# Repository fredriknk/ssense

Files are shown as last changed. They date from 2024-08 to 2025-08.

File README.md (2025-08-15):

# Mina Soilsense
 
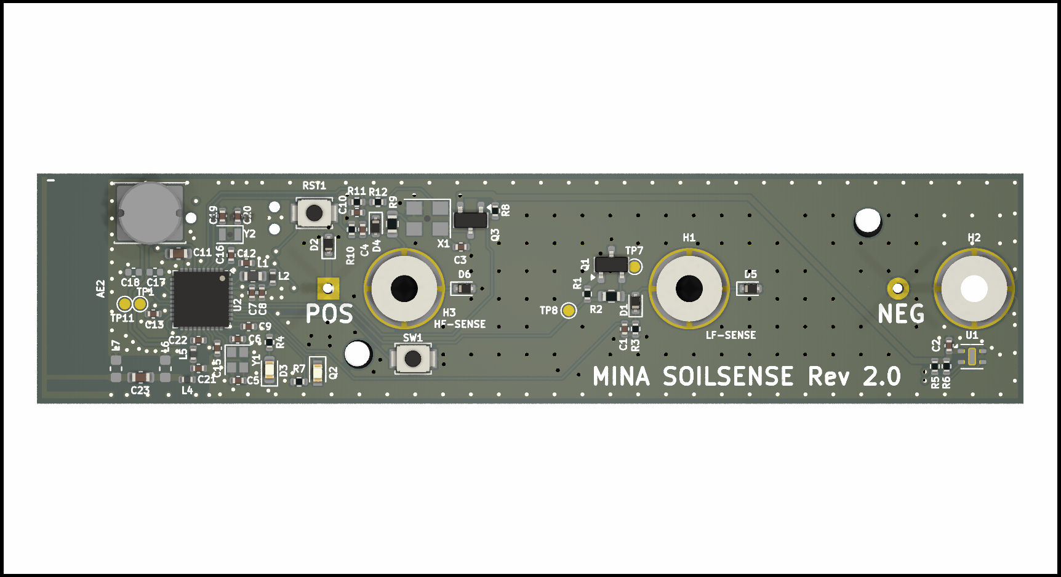
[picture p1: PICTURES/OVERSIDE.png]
HEADER


Open hardware for a Zigbee nrf52833 soil moisture probe, It is designed for using M3 stainless steel rods as probes screwed into the headers H1,H2,H3. It is designed to run on a 3.6v AA SAFT battery, average current is in the sub uA range when sampling 5 times per hour. So battery life should be in the range of 5-10 years. It has one 75mhz probe, one 1mhz probe (Variable frequency, so the plan is to do a frequency sweep with this to determine electrical conductivity in the medium) and a ground probe. It allso features a NFC coil, to pair the sensor with a gateway. And a temp sensor. 

Check out the ibom tool for component placement and hand soldering
[Assembly IBOM](https://htmlpreview.github.io/?https://raw.githubusercontent.com/fredriknk/ssense/main/DOCUMENTATION/ibom.html)

[PCB layout](./DOCUMENTATION/Board.pdf)

[SCHEMATIC](./DOCUMENTATION/Schematic.pdf)

## RF Testing

The antenna is simulated and optimized in matlab with [optimization script](https://github.com/fredriknk/antennasimulation) a theoretical -44dB S11, Actual measured S11 on the RF blanks is -26dB with a 0.5pF shunt capacotor soldered to L7 and a 0R resistor at C23. I left the antenna 1mm too long for tuning, but -26db is good enough for me. 

<p float="left">
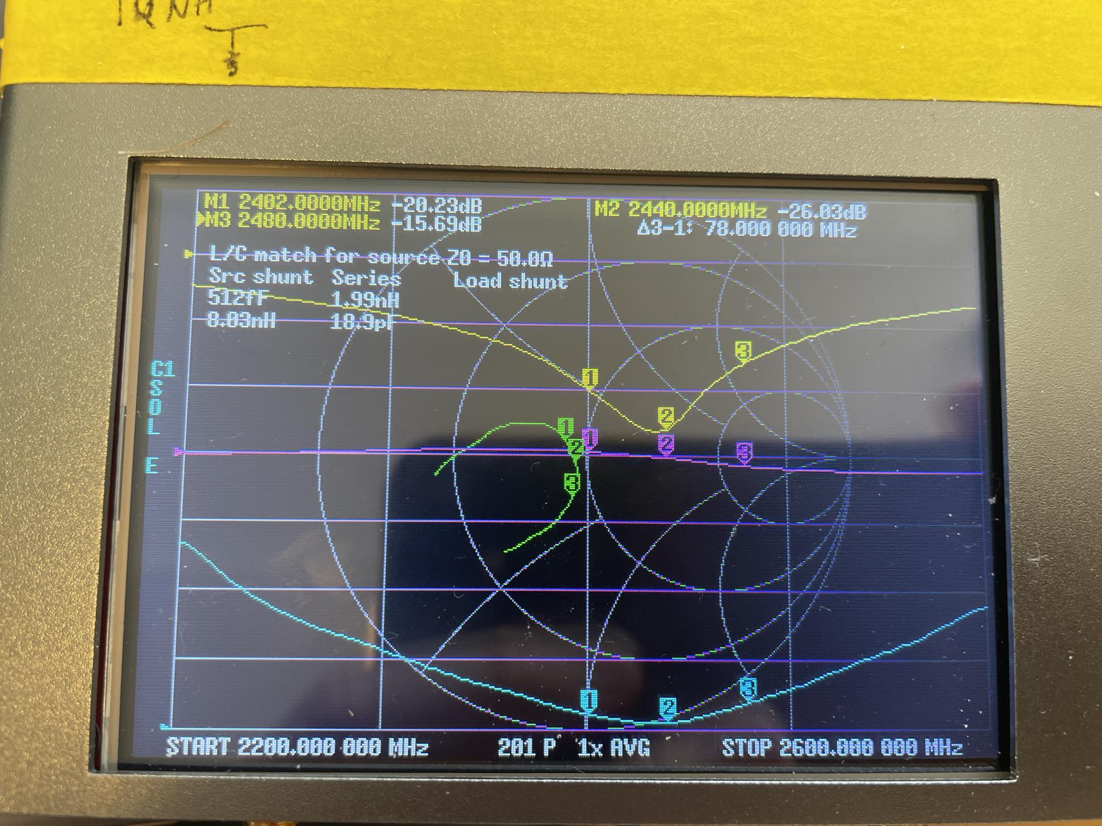
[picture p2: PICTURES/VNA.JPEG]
  
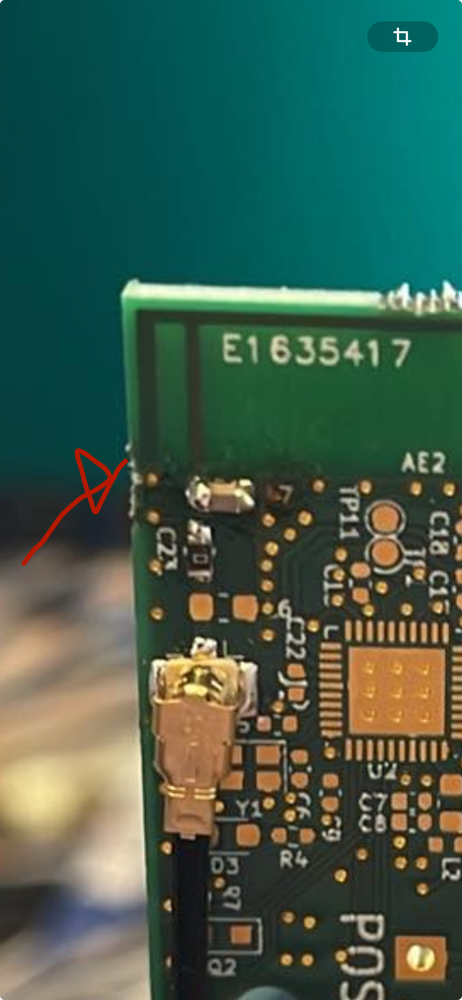
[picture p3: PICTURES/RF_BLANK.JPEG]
   
</p>

## Production run 1
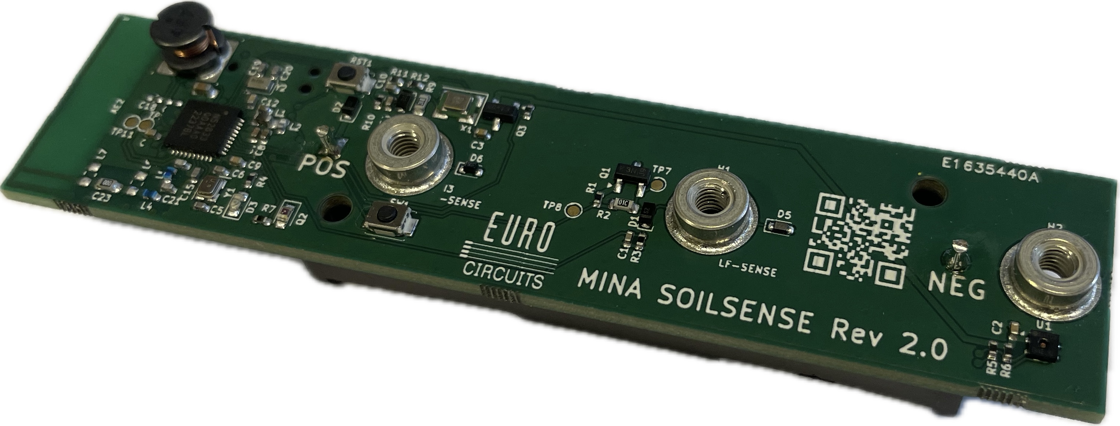
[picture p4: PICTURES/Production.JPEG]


Prototype produced at Eurocircuits

## Front

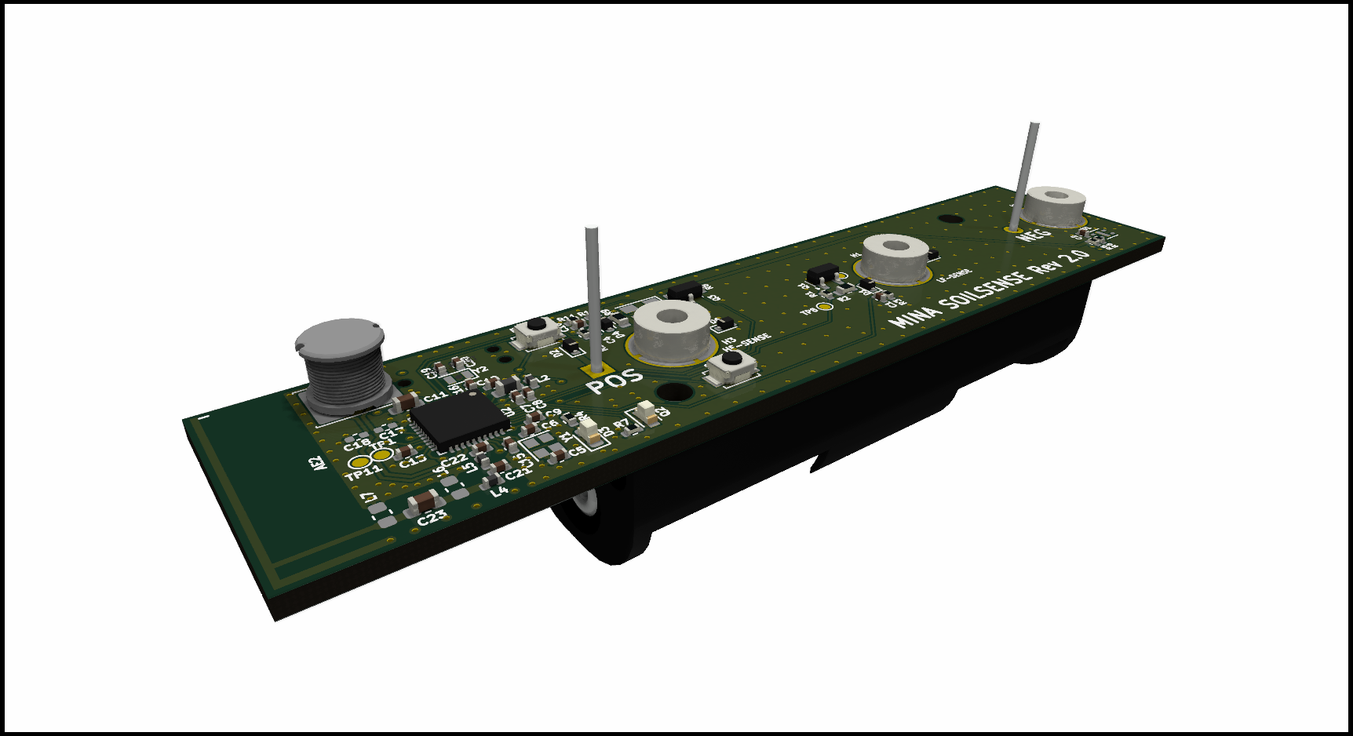
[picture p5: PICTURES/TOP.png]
Front


## Back

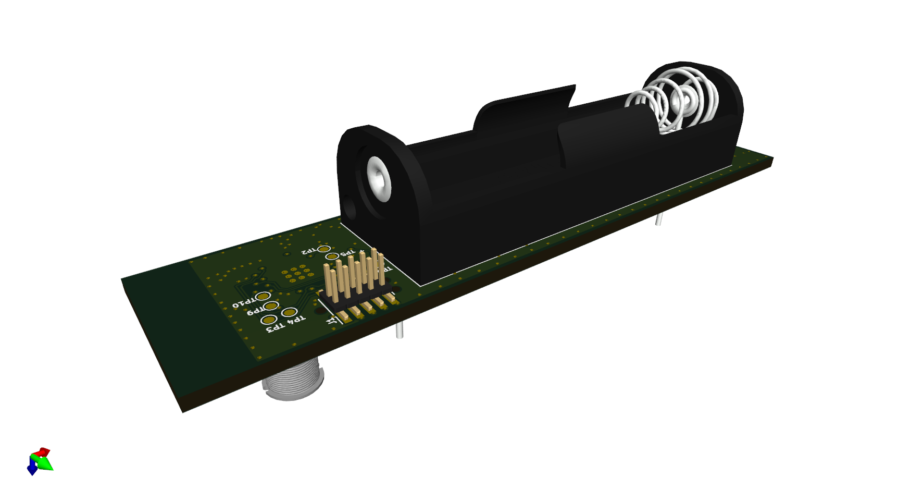
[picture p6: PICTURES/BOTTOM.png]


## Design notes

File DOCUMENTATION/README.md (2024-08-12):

## Use this folder for documentation, eg Schematics, datasheets, and stuff like that.

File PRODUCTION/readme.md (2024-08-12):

## All production files for latest revision of board

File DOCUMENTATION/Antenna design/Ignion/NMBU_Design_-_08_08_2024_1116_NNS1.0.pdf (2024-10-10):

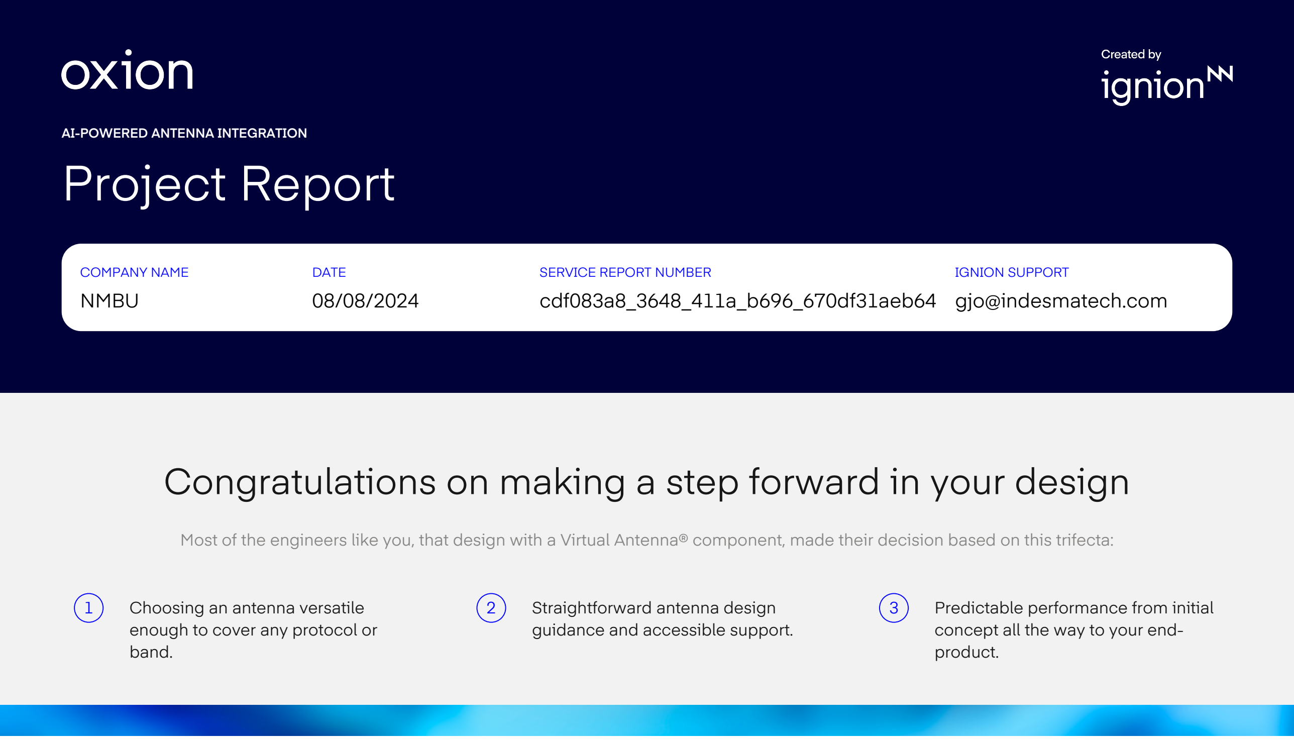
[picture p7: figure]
AI-POWERED ANTENNA INTEGRATION Project Report; COMPANY NAME NMBU; DATE 08/08/2024; SERVICE REPORT NUMBER cdf083a8_3648_411a_b696_670df31aeb64; IGNION SUPPORT gjo@indesmatech.com; Choosing an antenna versatile; enough to cover any protocol or band.; Straightforward antenna design; guidance and accessible support.; Predictable performance from initial; concept all the way to your end- product.

# Congratulations on making a step forward in your design

Most of the engineers like you, that design with a Virtual Antenna® component, made their decision based on this trifecta:

# Your requirements

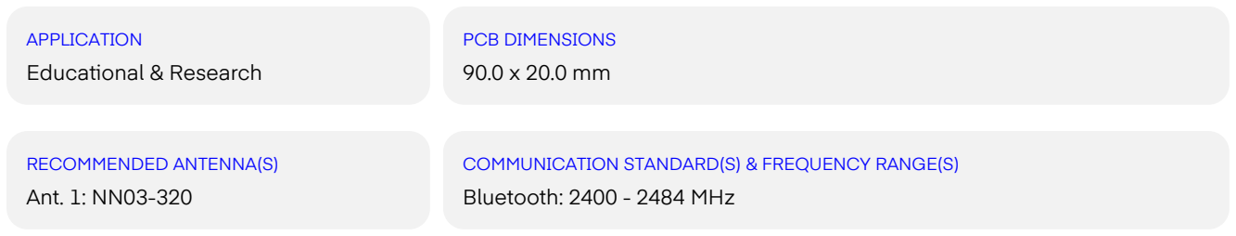
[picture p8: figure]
APPLICATION; Educational & Research; PCB DIMENSIONS; RECOMMENDED ANTENNA(S); Ant. 1: NN03-320; COMMUNICATION STANDARD(S) & FREQUENCY RANGE(S); Bluetooth: 2400 - 2484 MHz

# Best antenna placement on your PCB

Sketch of the proposed antenna placement and the recommended clearance area for the Virtual Antenna® component.

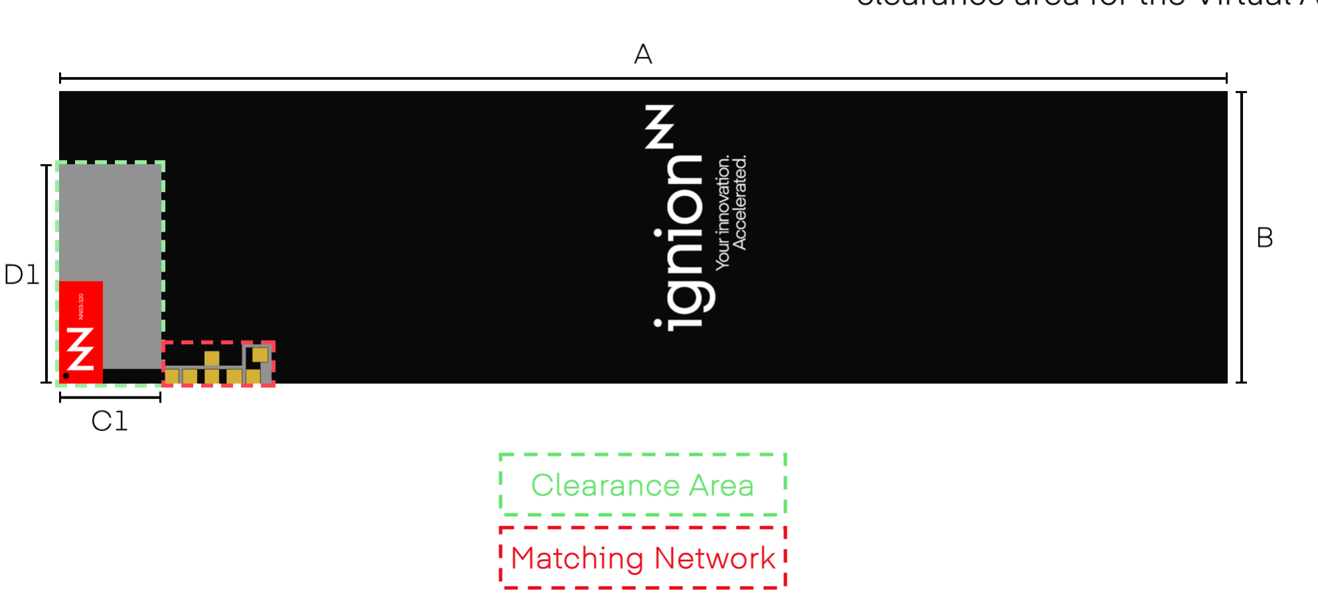
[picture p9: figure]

### PCB

Measure | mm
A | 90.0
B | 20.0

1: NN03-320

Measure | mm
C1 | 7.0
D1 | 15.0

The sketch above is an approximate representation of the PCB design. The accurate model can be found in the Desing_Files_NNS1.0.zip attached in the same email where the report was received.

1

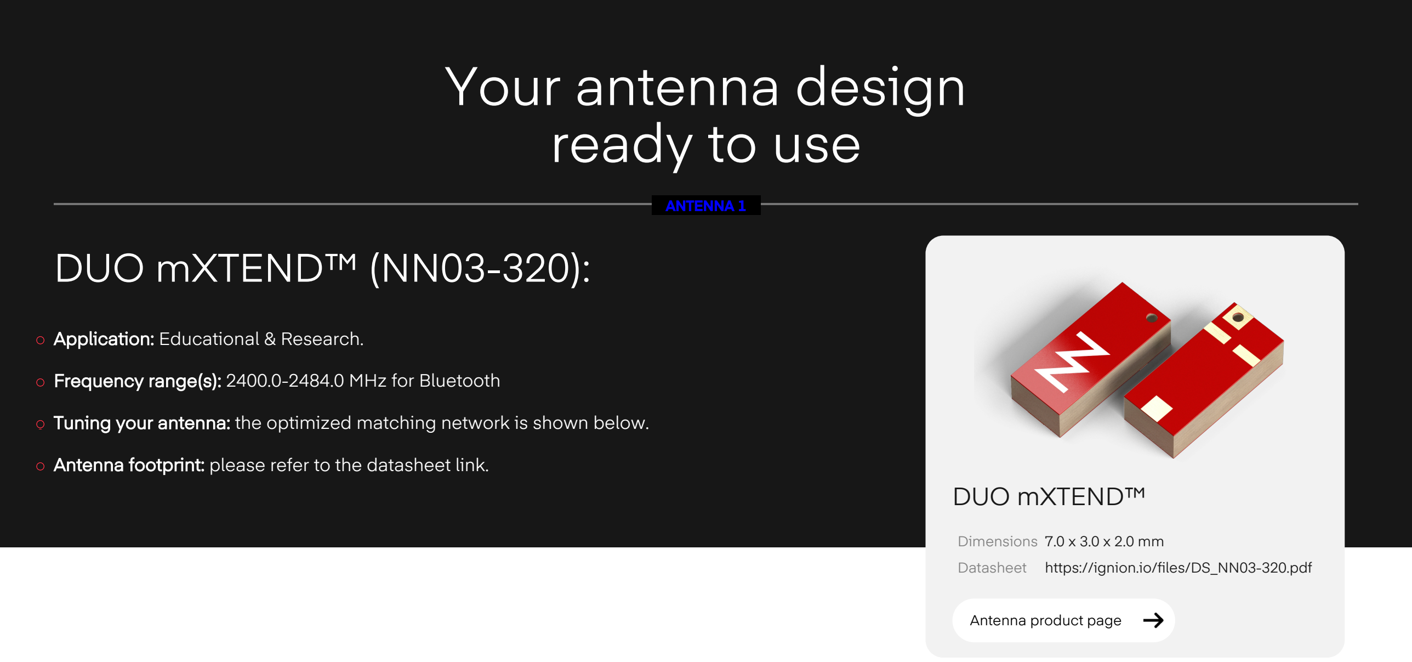
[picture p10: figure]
Your antenna design ready to use; ANTENNA 1; DUO mXTEND™ (NN03-320):; Application: Educational & Research.; DUO mXTEND™; Dimensions 7.0 x 3.0 x 2.0 mm; Datasheet; https://ignion.io/files/DS_NN03-320.pdf; Antenna product page

Frequency range(s): 2400.0-2484.0 MHz for Bluetooth

Tuning your antenna: the optimized matching network is shown below.

Antenna footprint: please refer to the datasheet link.

# Matching network antenna 1

Bluetooth matching network topology

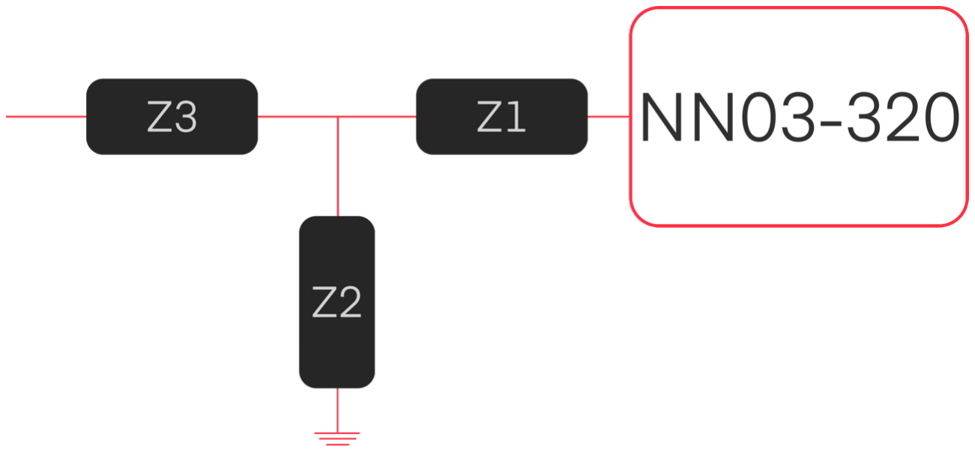
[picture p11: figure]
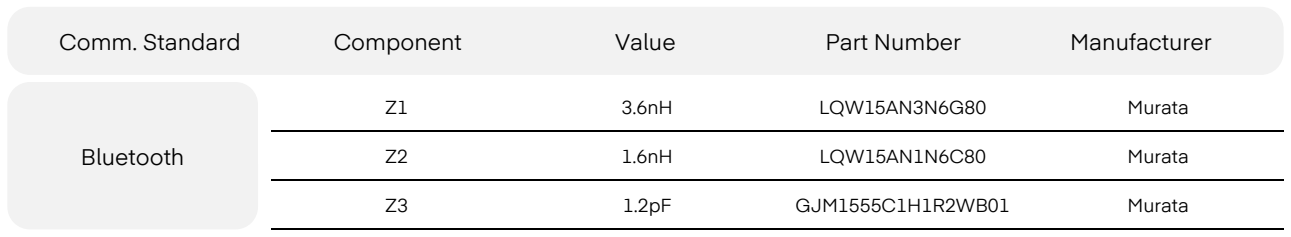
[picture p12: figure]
Bluetooth; LQW15AN3N6G80; Murata; LQW15AN1N6C80; GJM1555C1H1R2WB01

Comm. Standard | Component | Value | Part Number | Manufacturer

The electronic component values correspond with the matching network when implemented on a bare PCB. These values may need further tuning and optimization when additional elements such as batteries, plastic covers, connectors, displays, etc. are added to your final device.

If you need further assistance, please contact our antenna specialists.

GET HELP | 2

# Your antenna design ready to use

ANTENNA 1

# Your design overall performance

# Expected device performance with antenna 1

Your prototype using the NN03-320 antenna is expected to achieve the reflection coefficient (in dB) and total efficiency (in %) as shown in this graph.

Rule of thumb: it is desirable to have a reflection coefficient below -6 dB, ensuring proper impedance matching of the antenna component and optimized
total efficiency.

INCREASE YOUR PERFORMANCE: to increase the performance we recommend evaluating your PCB again with increased dimensions (increasing length by 10 mm typically results in a total efficiency improvement of 0.5 dB).

Frequency (MHz) | 2400 | 2484 | Avg 2400 - 2484

If you need further assistance, please contact our antenna specialists.

GET HELP | 3

# General design recommendations

### for performance optimization with Virtual Antenna® technology

Consider the recommended clearance area in all directions around the antenna component. It must be free from electronic components, traces and ground plane in all PCB layers including the area underneath the antenna.

### 2 ANTENNA LOCATION

Keep the antenna in a corner of the PCB, as far as possible from other metalic components.

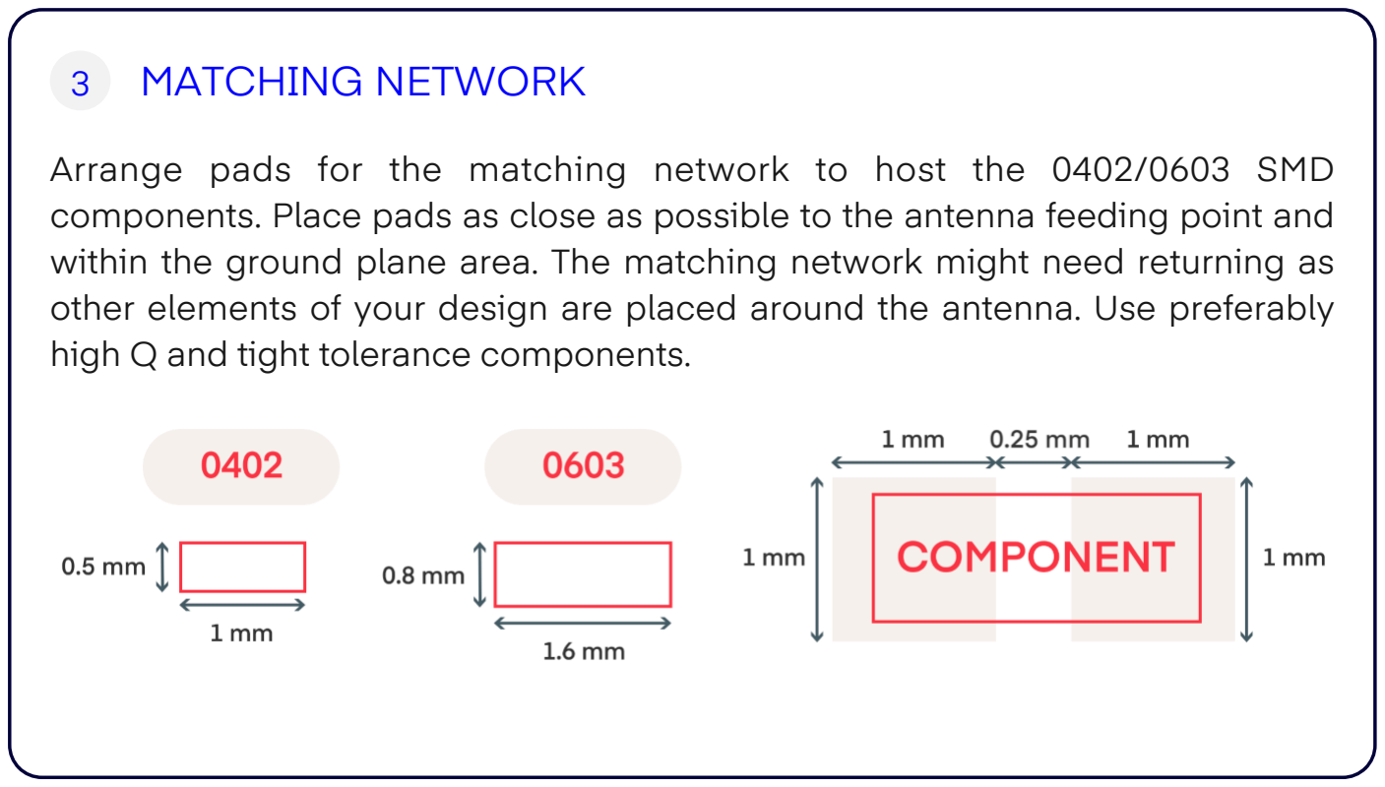
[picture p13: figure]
MATCHING NETWORK; high Q and tight tolerance components.

Arrange pads for the matching network to host the 0402/0603 SMD components. Place pads as close as possible to the antenna feeding point and within the ground plane area. The matching network might need returning as other elements of your design are placed around the antenna. Use preferably

### 4 MATERIALS

Use low loss materials (i.e. PET plastic, Polyethylene Terephthalate) for the housings and enclosures.

### 5 MULTI-LAYER PCBs

Ensure that all the grounding sections in every PCB layer are properly connected through vias.

### 6 TRANSMISSION LINE AND RF CHIP

Design your transmission line connecting the matching network to your RF chip so that its characteristic impedance is 50 Ohms. Locate your RF chip as close as possible to the matching network to reduce losses.

### 7 GROUND PLANE LAYER

Ensure a continuous conducting ground plane in at least one layer of your PCB. Always maximize the surface of your ground area on the PCB of your device to maximize its radiation performance.

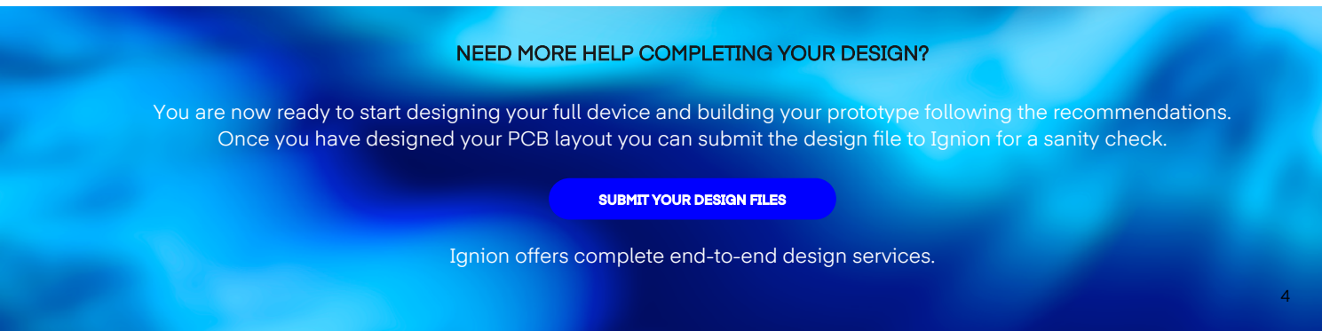
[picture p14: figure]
NEED MORE HELP COMPLETING YOUR DESIGN?; SUBMIT YOUR DESIGN FILES

You are now ready to start designing your full device and building your prototype following the recommendations. Once you have designed your PCB layout you can submit the design file to Ignion for a sanity check.

Ignion offers complete end-to-end design services.

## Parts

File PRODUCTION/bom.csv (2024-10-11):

Designator | Footprint | Quantity | Value | LCSC Part #
BT1 | BatteryHolder_Keystone_2460_1xAA | 1 | Keystone 2460 | 2460
C1, C10, C4 | 0402 | 3 | 1nF
C11 | 0603 | 1 | 4.7uF
C12, C8 | 0402 | 2 | 1uF
C13, C16, C2, C3, C9 | 0402 | 5 | 100nF
C15 | 0402 | 1 | 100pF
C19, C20, C5, C6 | 0402 | 4 | 12pF
C21 | 0402 | 1 | 1.2pF
C22 | 0402 | 1 | 1.0pF
C23 | 0603 | 1 | 0R placeholder
C7 | 0402 | 1 | 47nF
D1, D2, D4 | D_SOD-523 | 3 | CDSU101A | CDSU101A
D3 | 0603 | 1 | LED
D5, D6 | D_SOD-523 | 2 | Zener Prot 5V | EDZVT2R5.1B
H1, H2, H3 | Mounting_Wuerth_WA-SMSI-M3_H2.5mm_9774025360 | 3 | 9774025360R | 9774025360R
J1 | SEXY_pinpogo | 1 | JLINK
L1 | 0603 | 1 | 10uH
L2 | 0402 | 1 | 15nH | MLG1005S15NHT000
L3 | L_Bourns_SDSS604A | 1 | 4.7uH | SDR0604-4R7ML
L4 | 0402 | 1 | 2.2nH | LQW15AN2N2C80D
L5 | 0402 | 1 | 4.7nH | LQW15AN4N7C80D
Q1 | SOT-23 | 1 | MMBT3906
Q2 | PHOTOTRANS_1708Metric | 1 | Q_Photo_NPN | ALS-PT19-315C/L177/TR8
Q3 | SOT-23 | 1 | IRLML6401 | IRLML6401
R1, R11, R12, R5, R6, R8 | 0402 | 6 | 10k
R10, R3 | 0402 | 2 | 1M
R2, R9 | 0603 | 2 | 10k
R4 | 0402 | 1 | 1k
R7 | 0402 | 1 | 470R
RST1, SW1 | SW_SPST_B3U-1000P-B | 2 | B3U-1000P
U1 | Sensirion_DFN-4-1EP_2x2mm_P1mm_EP0.7x1.6mm | 1 | SHTC3
U2 | QFN-40-1EP_5x5mm_P0.4mm_EP3.6x3.6mm_ThermalVias | 1 | nRF52833_QDxx | nRF52833_QDAA
X1 | Oscillator_SMD_SeikoEpson_SG8002CE-4Pin_3.2x2.5mm | 1 | KC3225K75.0000C1GE00 | KC3225K75.0000C1GE00
Y1 | Crystal_SMD_2016-4Pin_2.0x1.6mm | 1 | 32MHz | XRCGB32M000F2P01R0
Y2 | Crystal_SMD_2012-2Pin_2.0x1.2mm | 1 | 32.768kHz | CM8V-T1A-32.768KHZ-9PF-20PPM-TA-QC

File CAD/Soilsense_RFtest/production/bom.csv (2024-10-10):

Designator | Footprint | Quantity | Value | LCSC Part #
BT1 | BatteryHolder_Keystone_2460_1xAA | 1 | Keystone 2460 | 2460
C23 | 0603 | 1 | 0R placeholder
H1, H2, H3 | Mounting_Wuerth_WA-SMSI-M3_H2.5mm_9774025360 | 3 | 9774025360R | 9774025360R
J2 | U.FL_Hirose_U.FL-R-SMT-1_Vertical | 1 | Conn_Coaxial

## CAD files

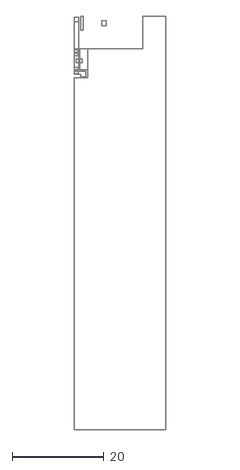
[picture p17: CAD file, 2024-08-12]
DOCUMENTATION/Antenna design/Ignion/Top.dxf
20.0 x 90.0

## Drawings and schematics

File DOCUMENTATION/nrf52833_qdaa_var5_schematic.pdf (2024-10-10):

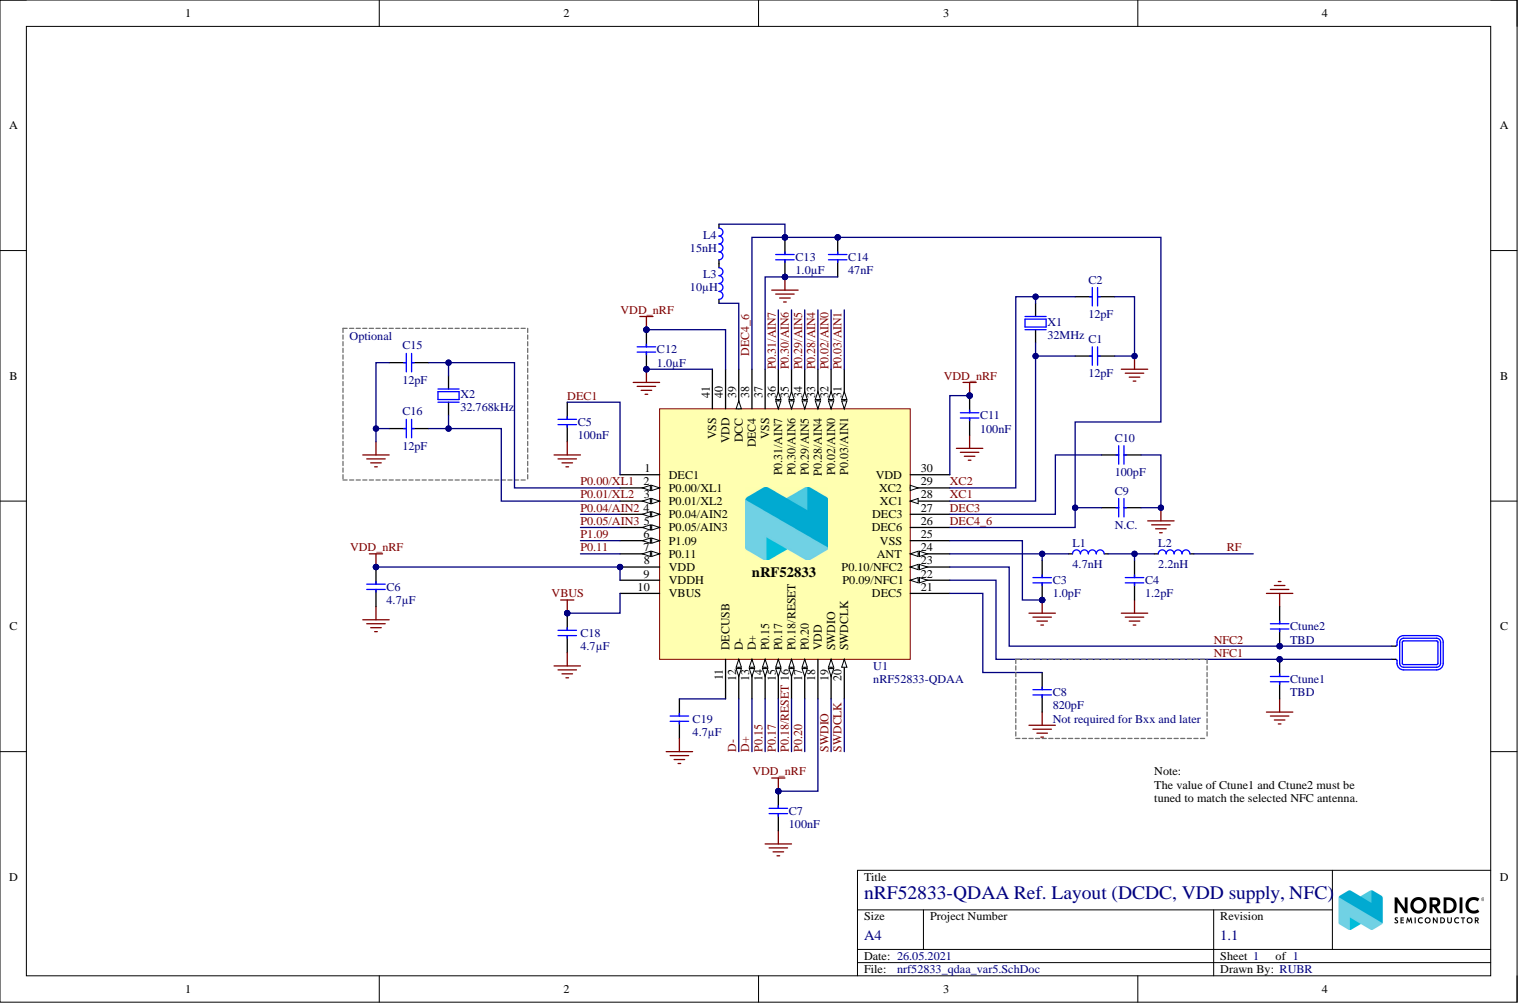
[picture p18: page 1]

VBUS 10

NFC1

Not required for Bxx and later

Note:
The value of Ctune1 and Ctune2 must be
tuned to match the selected NFC antenna.

Title
nRF52833-QDAA Ref. Layout (DCDC, VDD supply, NFC)

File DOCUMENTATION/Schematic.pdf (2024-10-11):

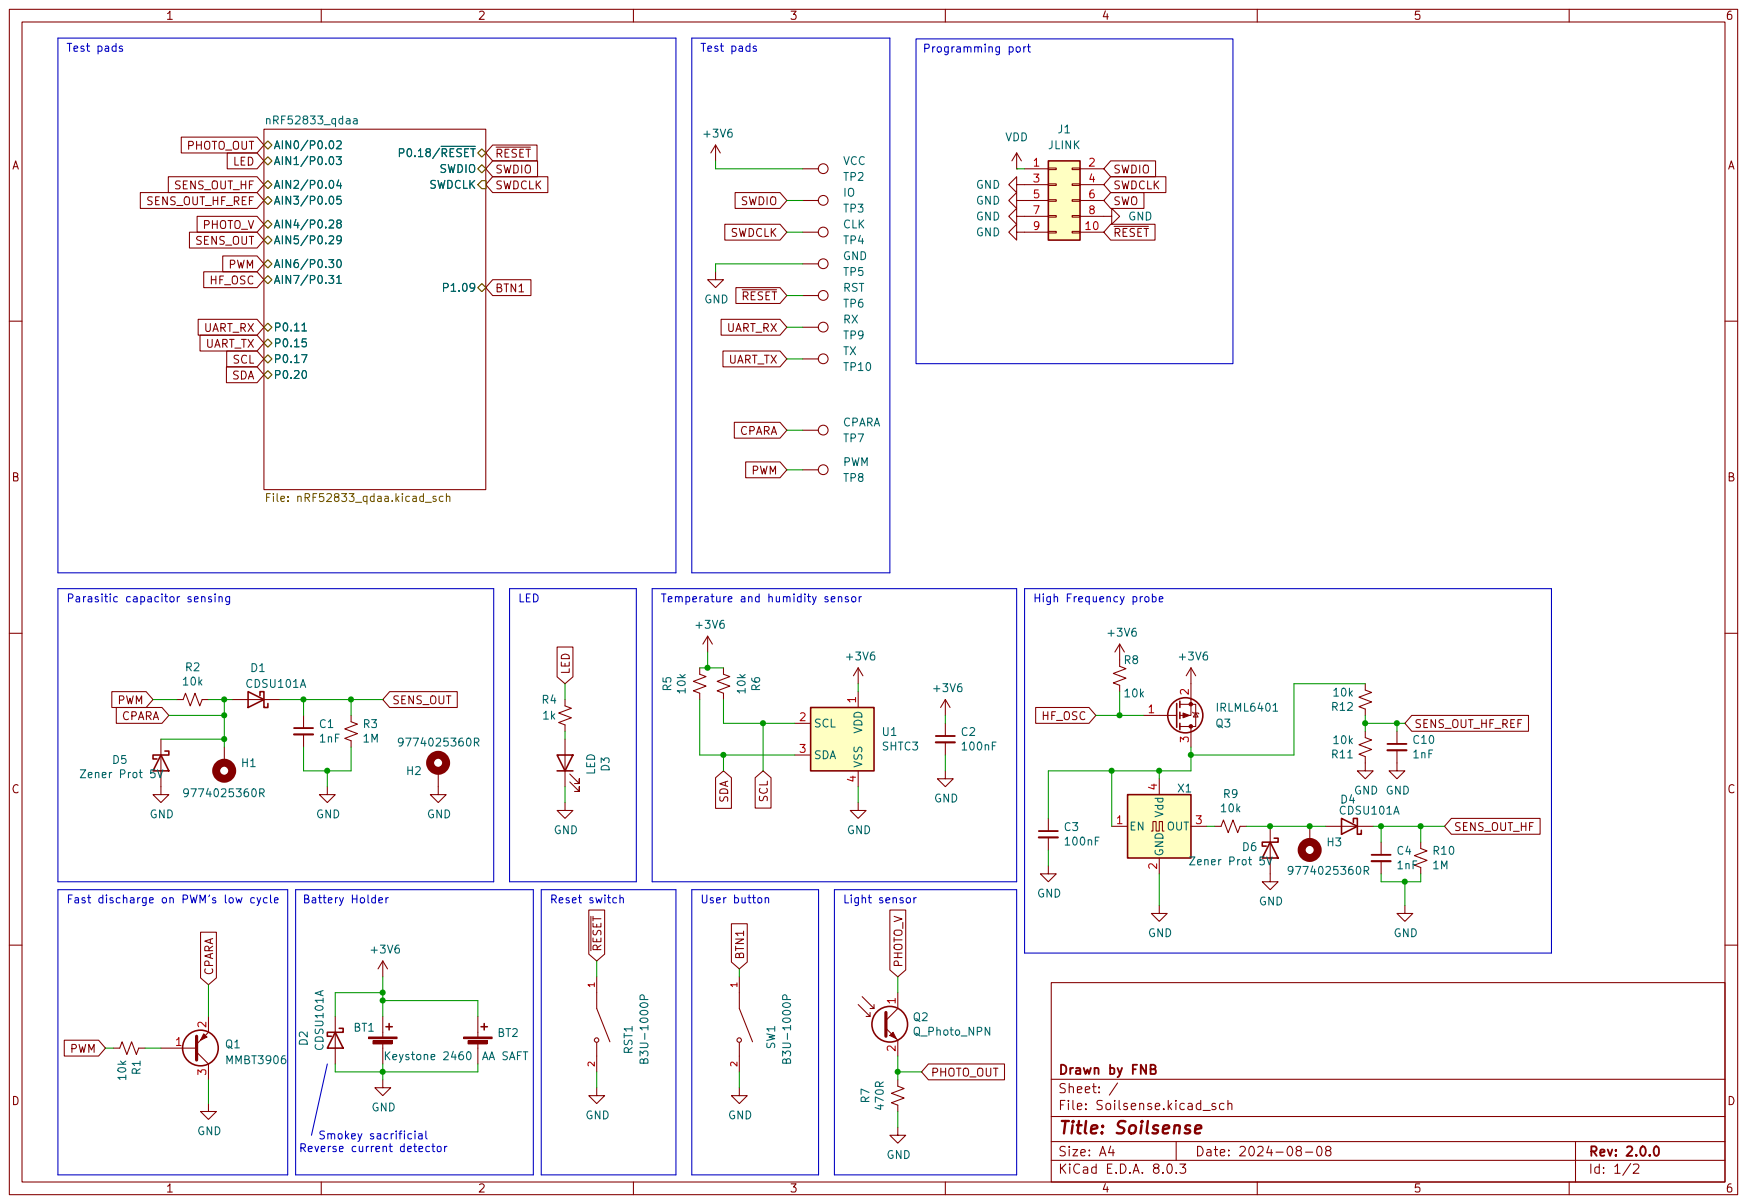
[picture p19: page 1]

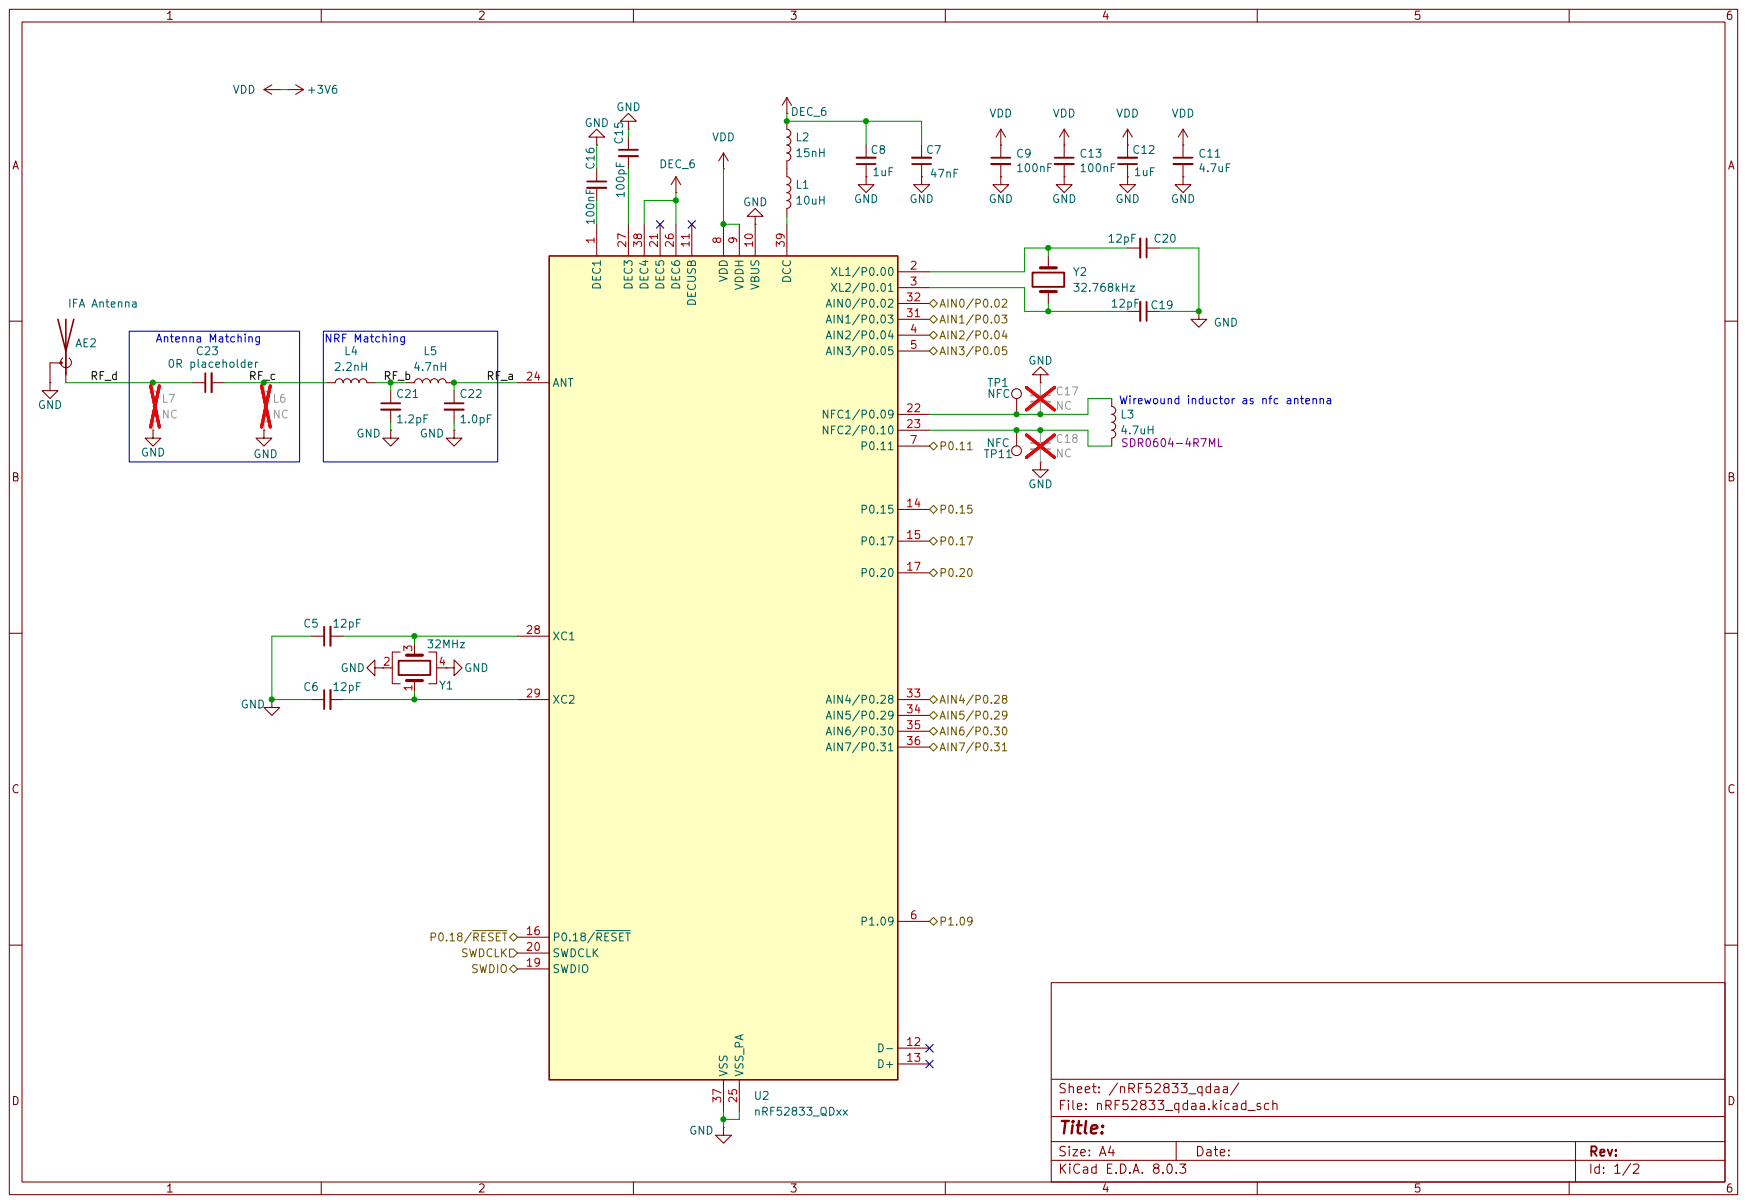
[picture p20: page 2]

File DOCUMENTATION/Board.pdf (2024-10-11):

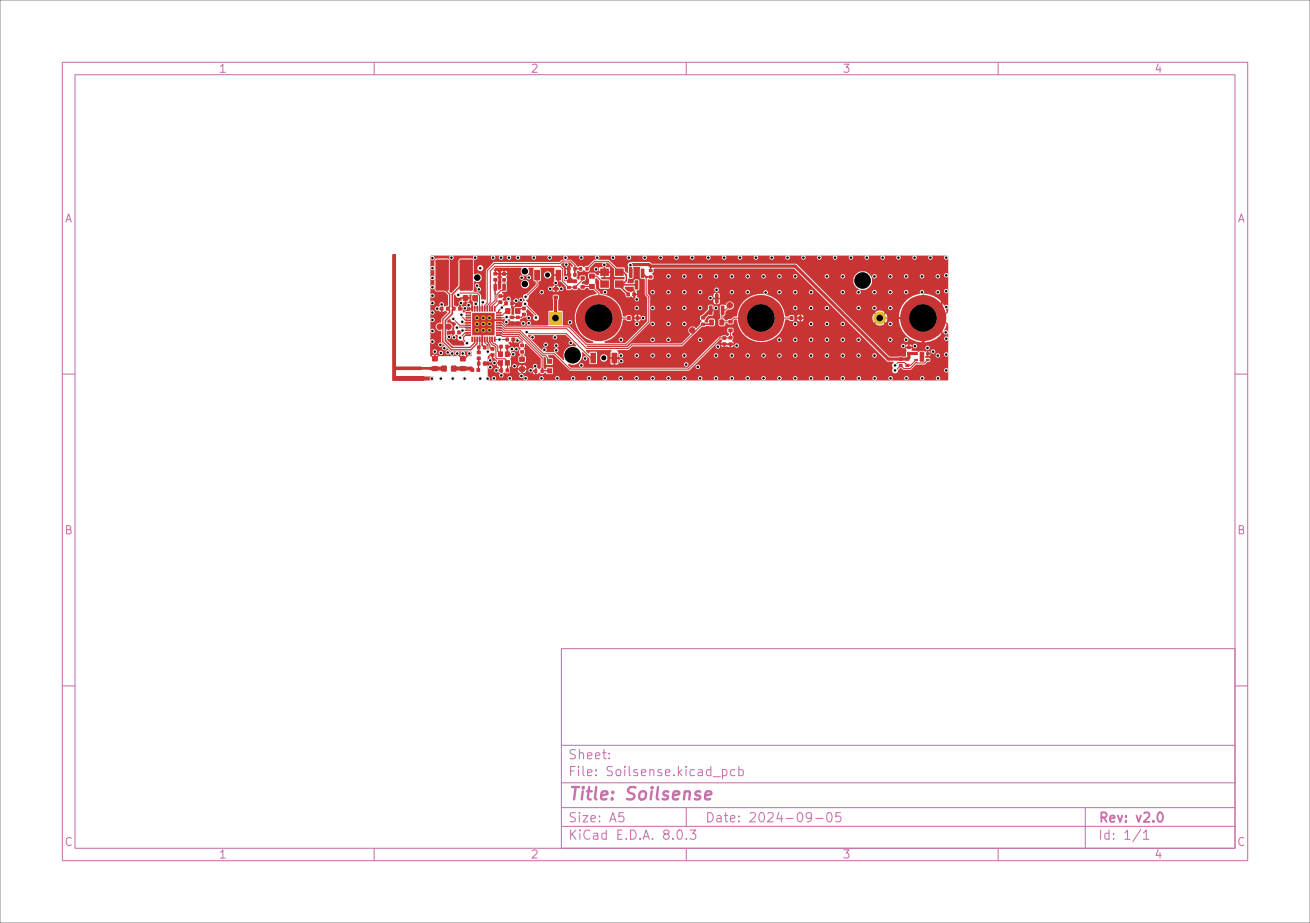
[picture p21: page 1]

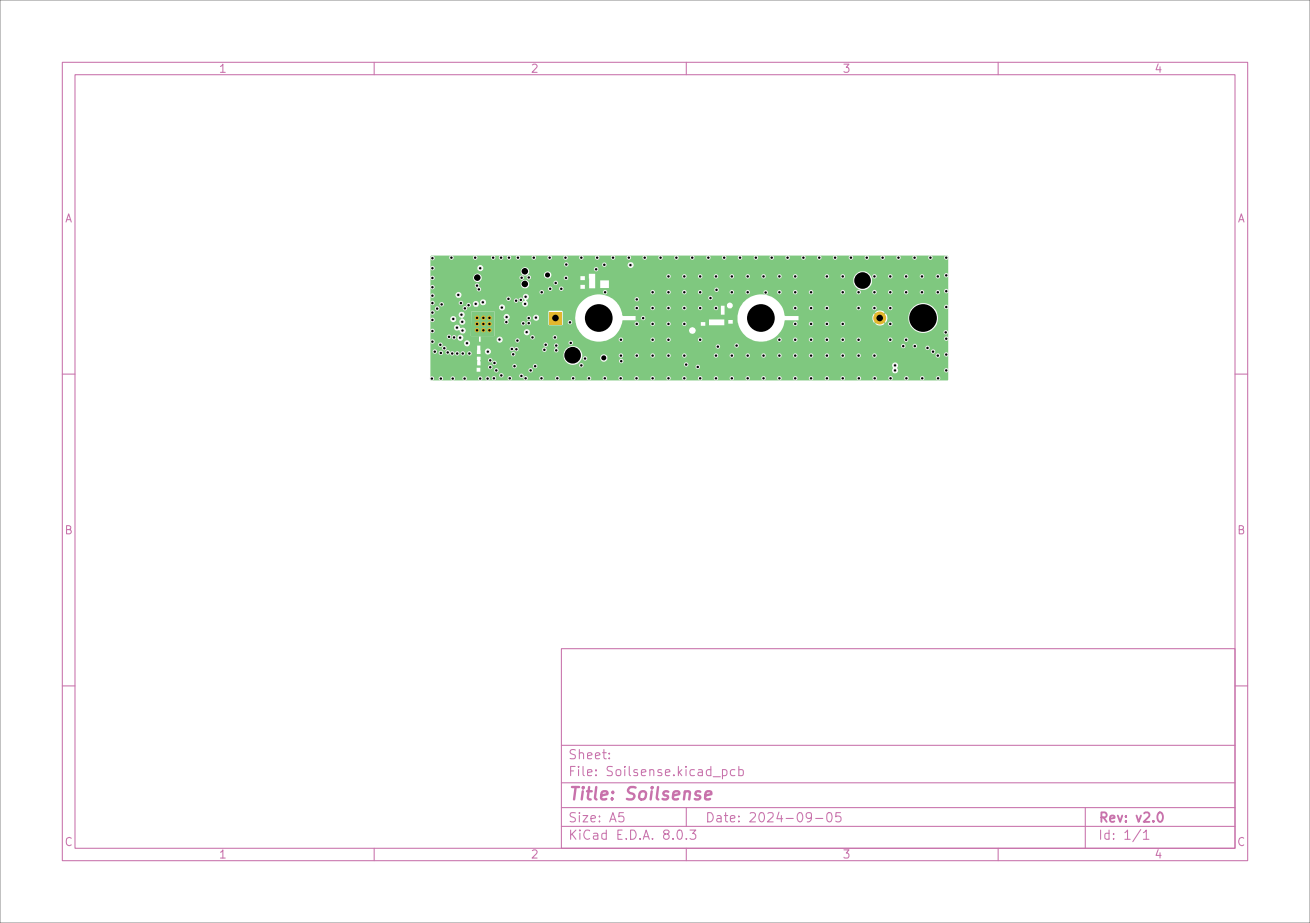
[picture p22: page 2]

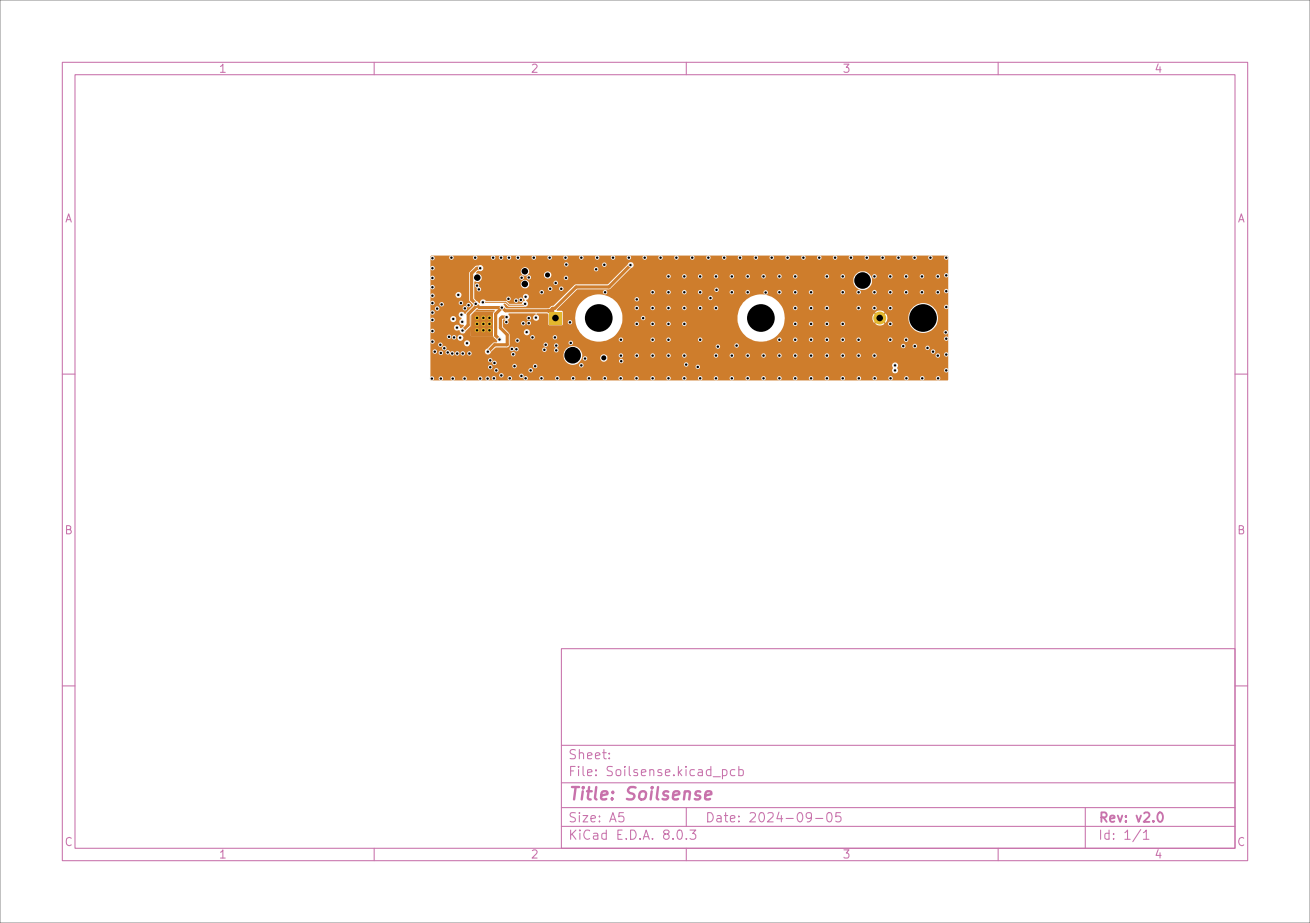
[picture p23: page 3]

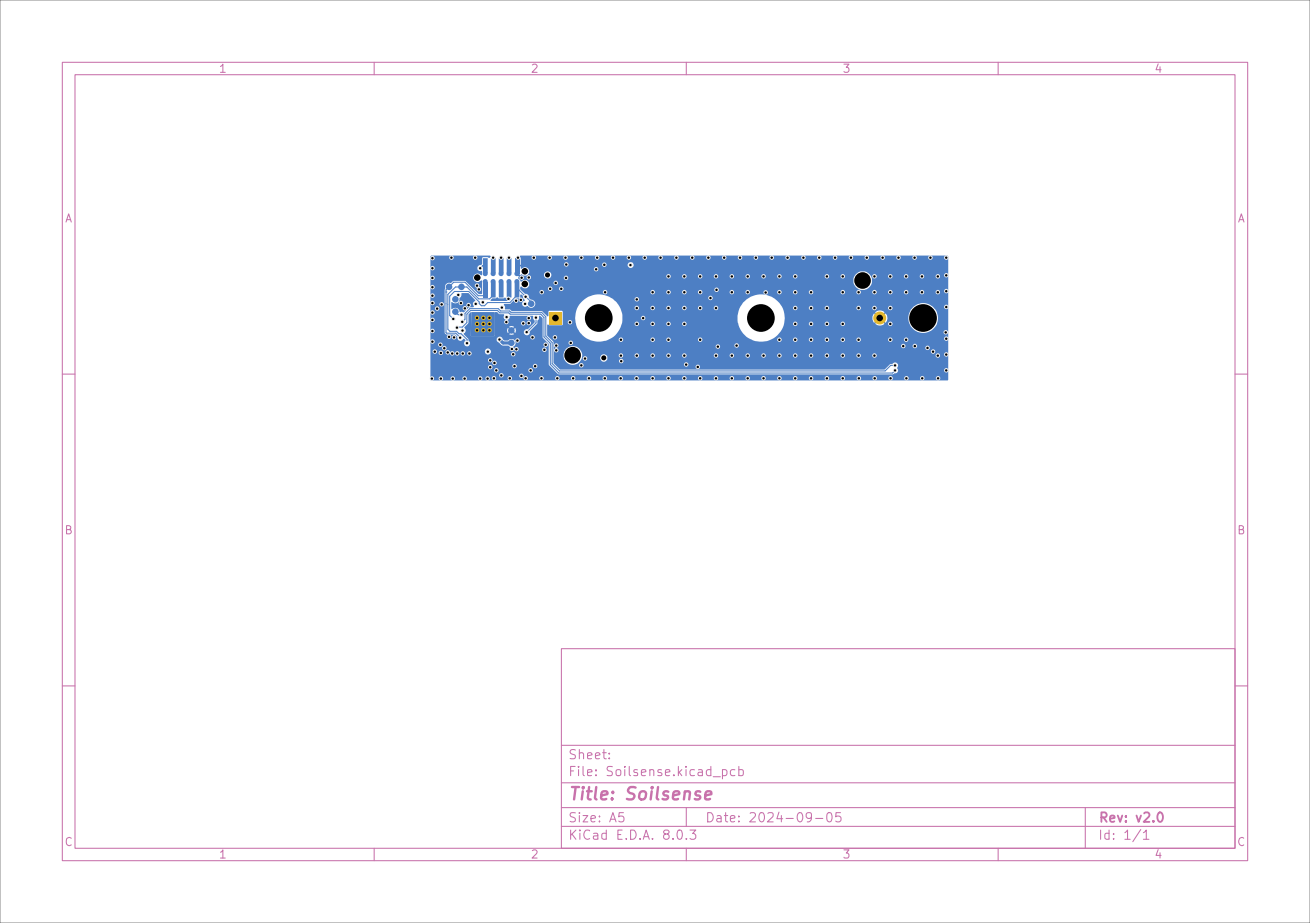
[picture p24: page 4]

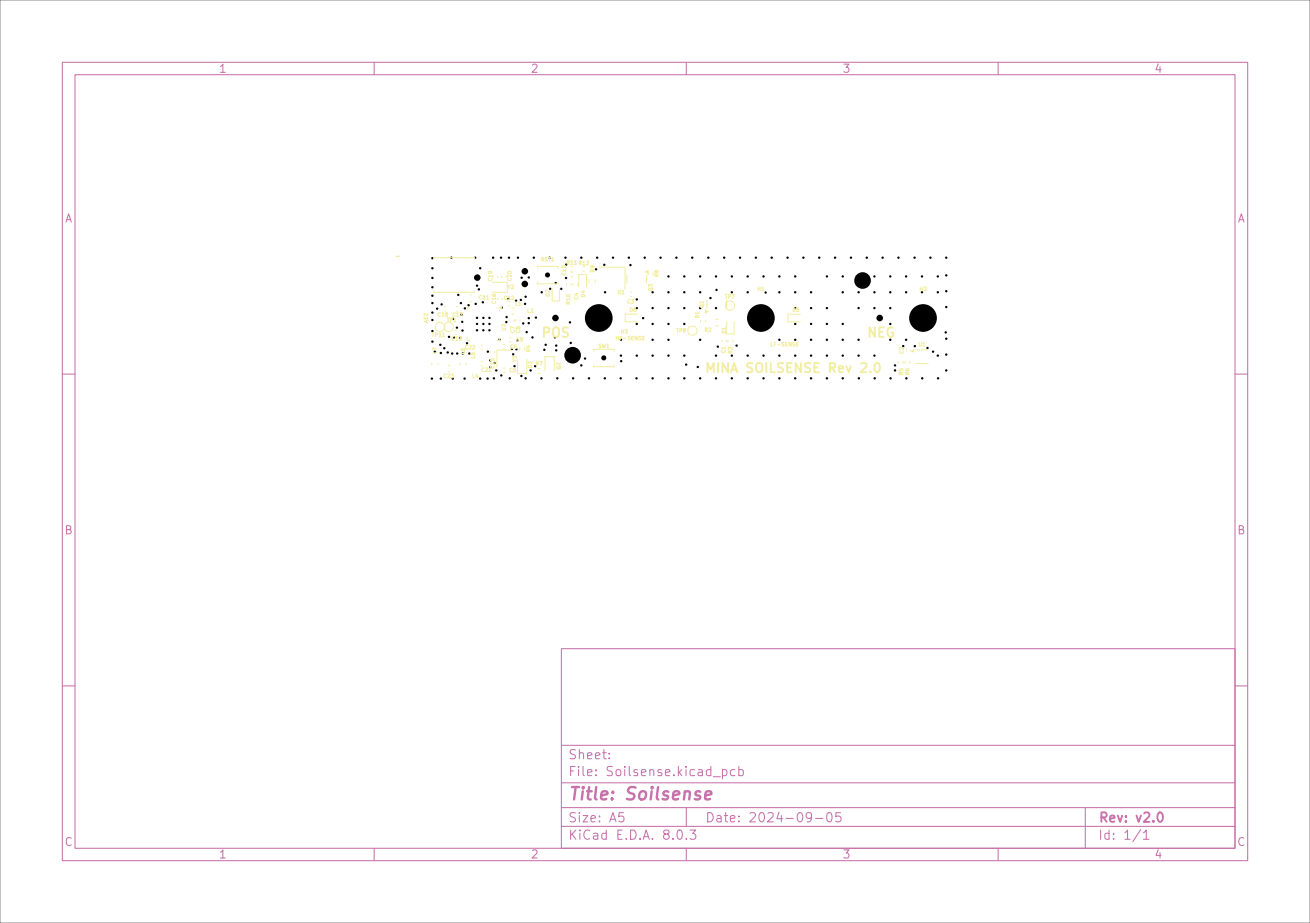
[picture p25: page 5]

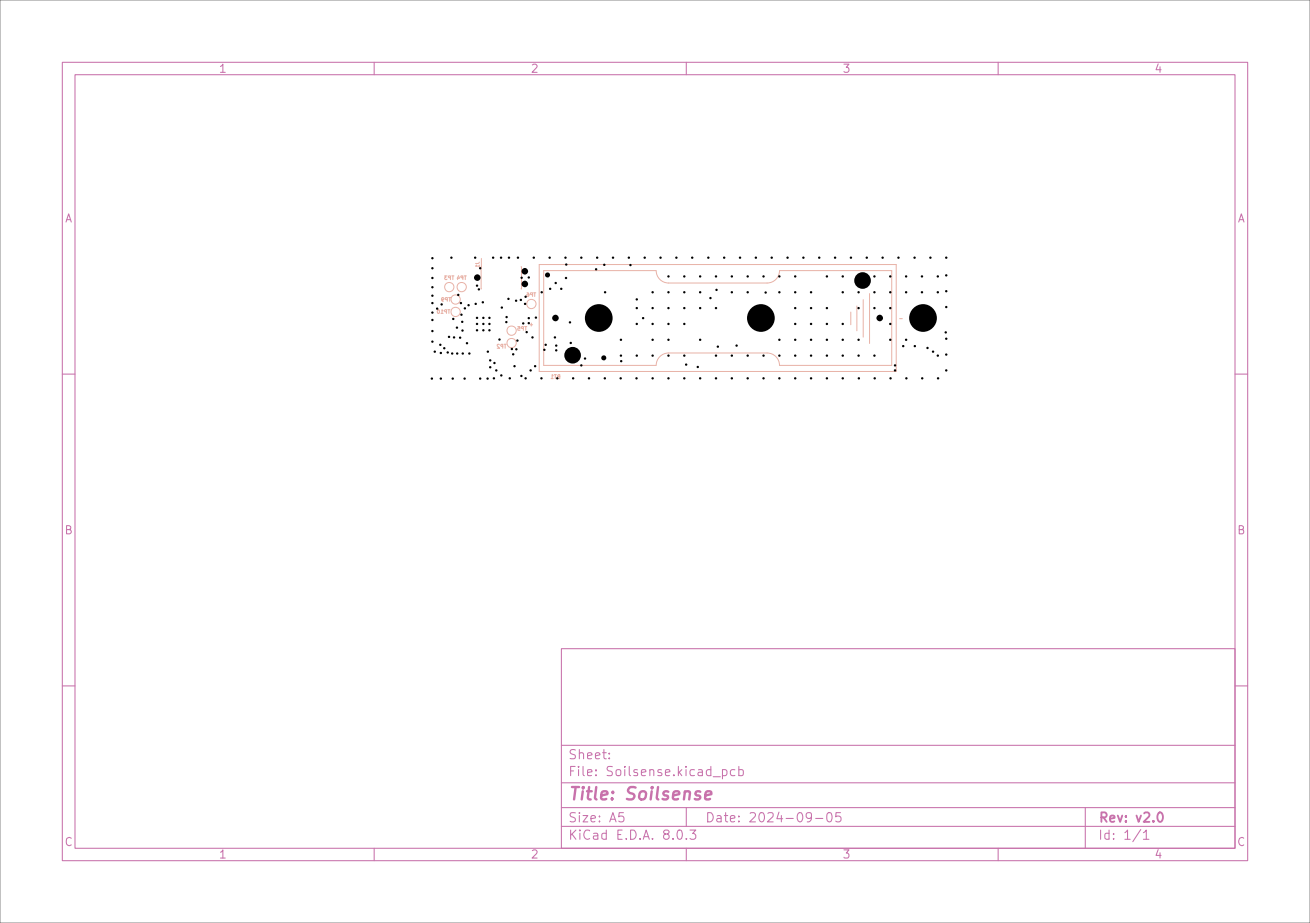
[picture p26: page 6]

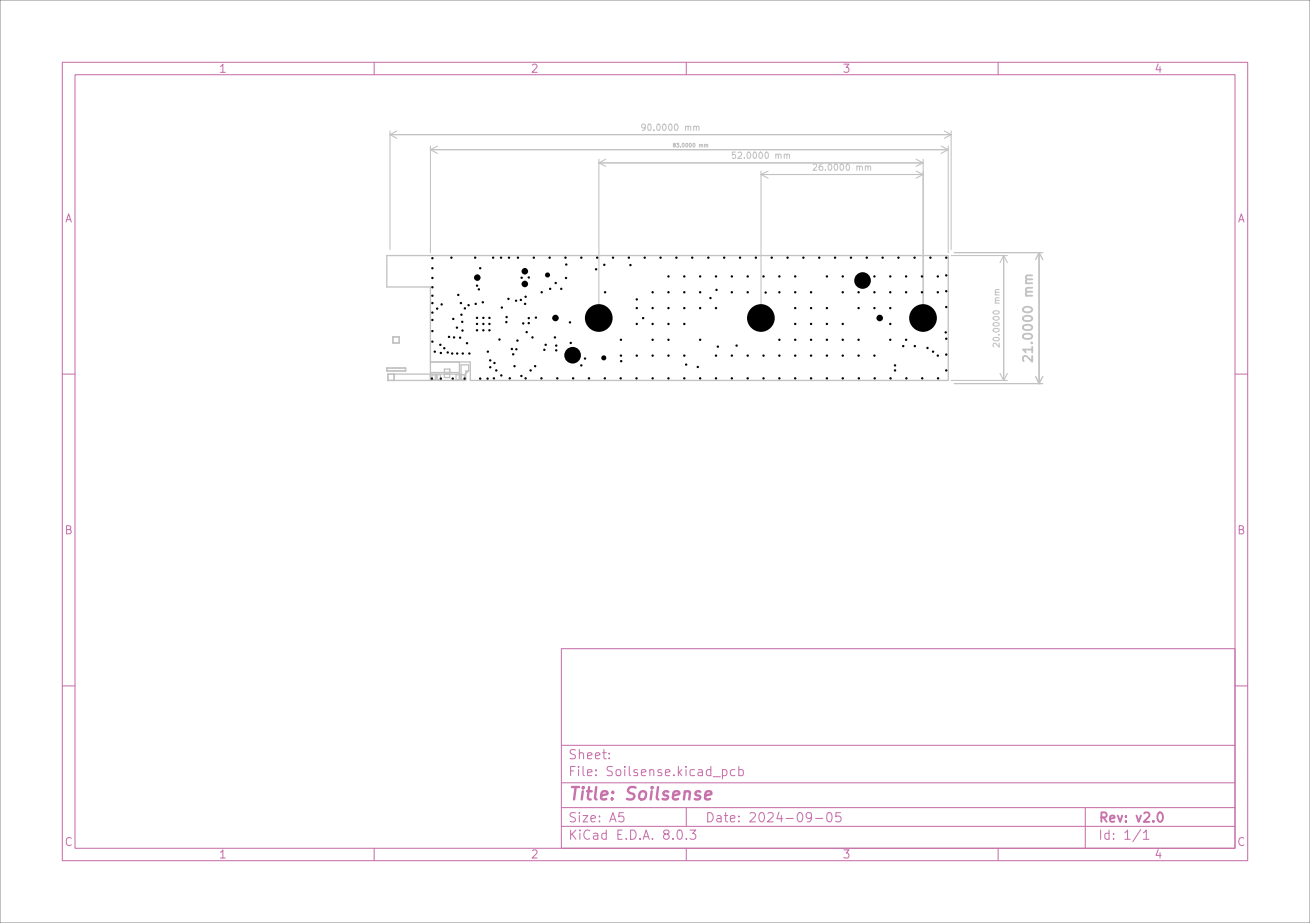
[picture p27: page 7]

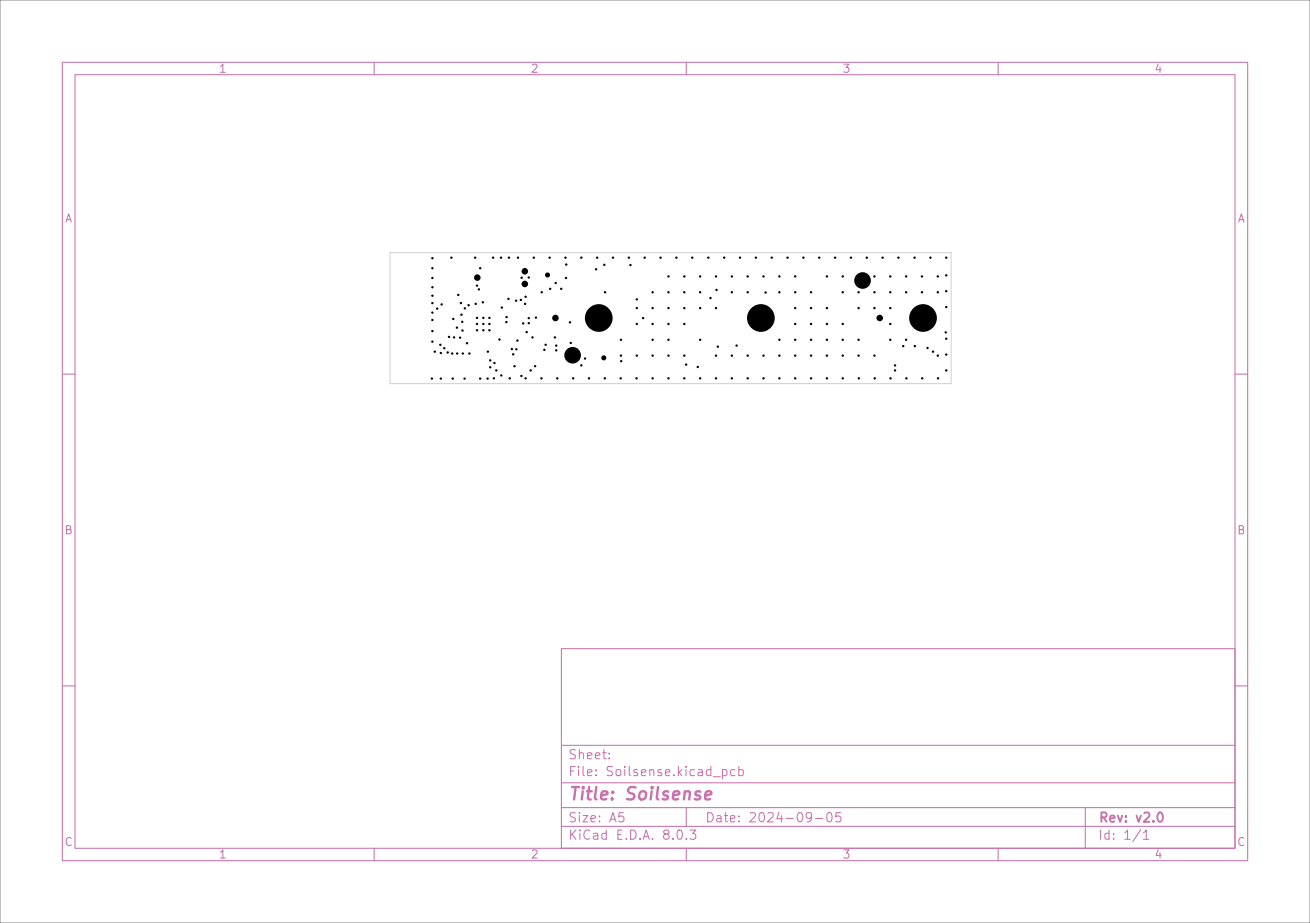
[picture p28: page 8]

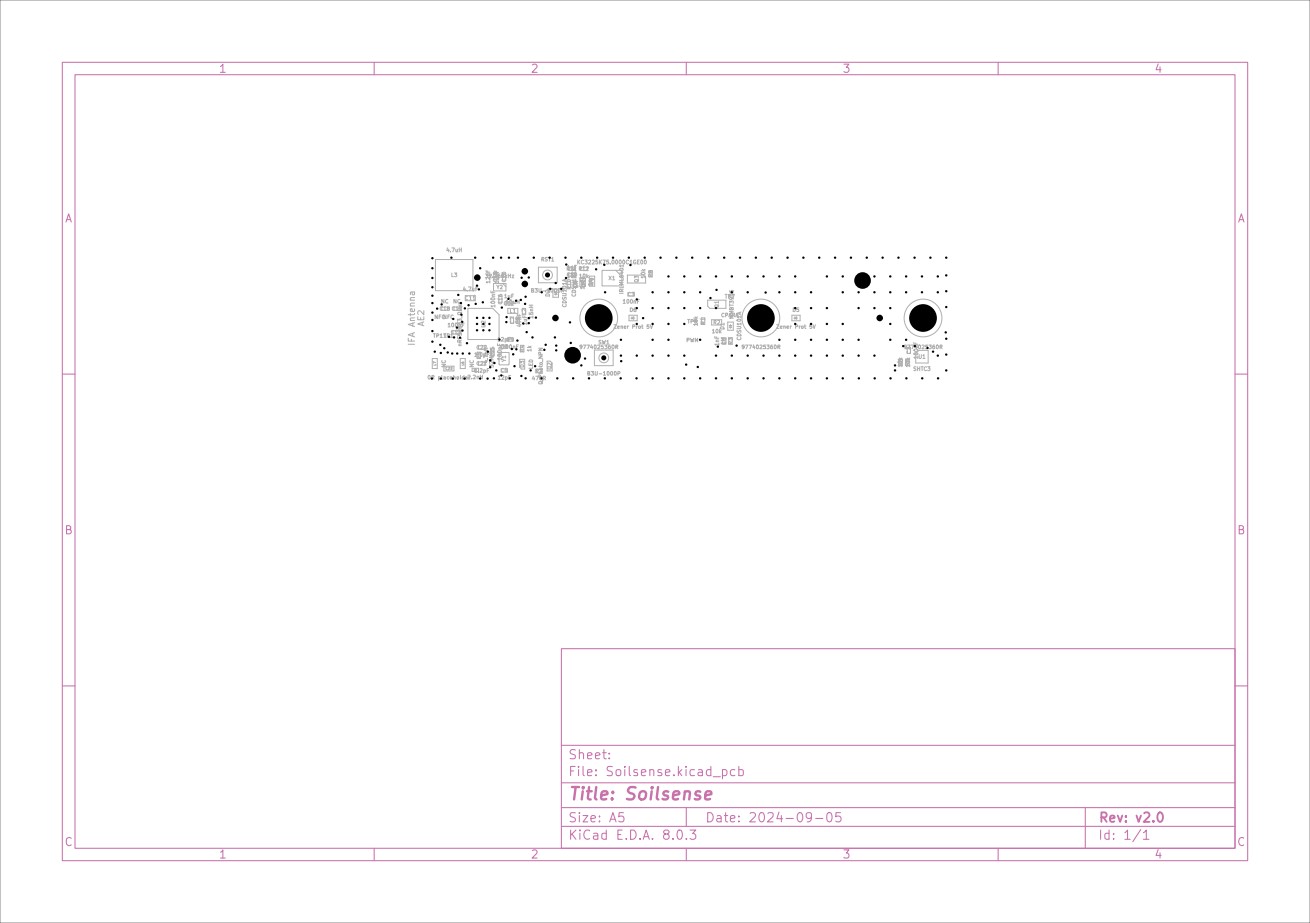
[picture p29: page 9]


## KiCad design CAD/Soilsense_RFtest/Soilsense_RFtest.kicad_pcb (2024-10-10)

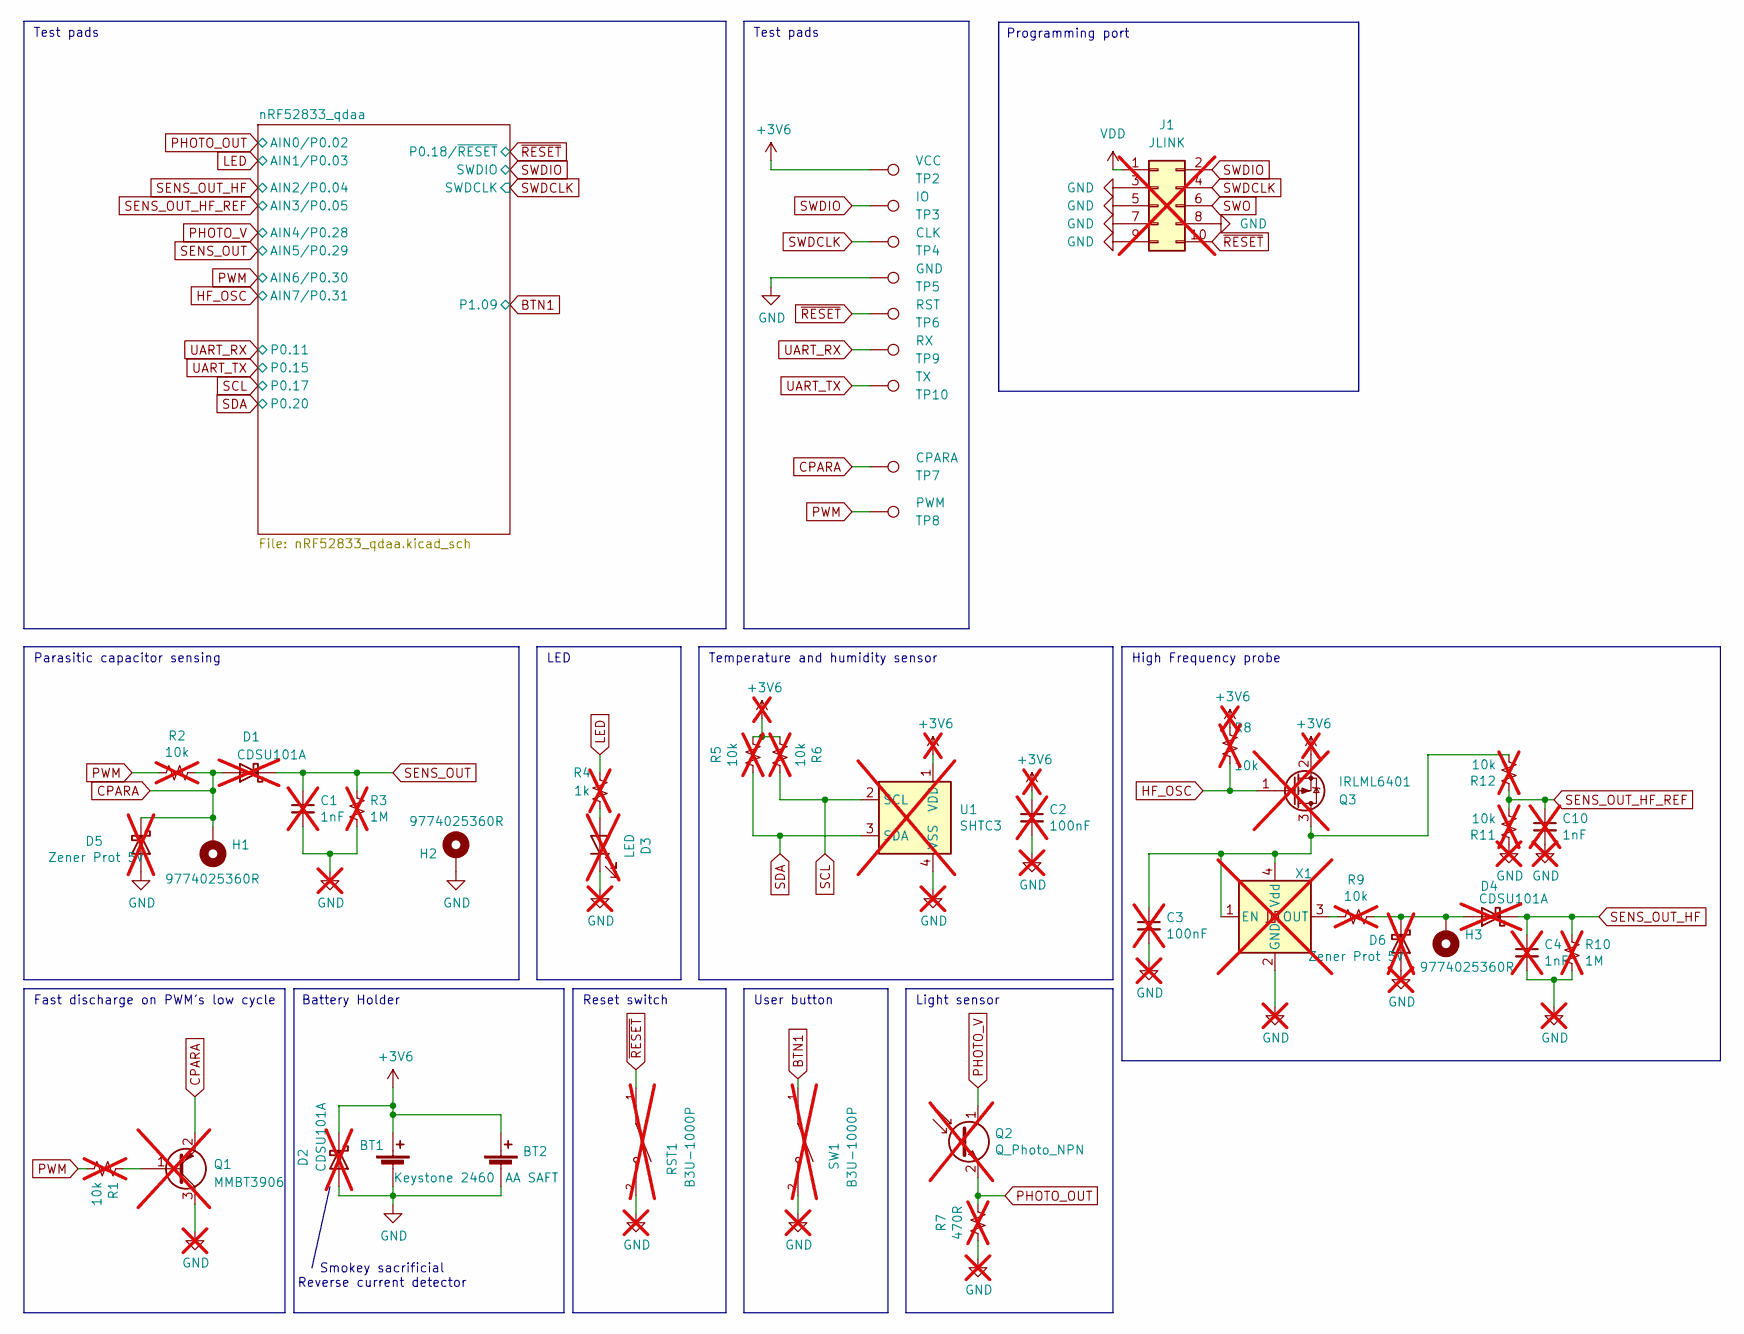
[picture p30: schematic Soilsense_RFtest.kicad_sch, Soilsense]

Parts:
BT1: Keystone 2460; BatteryHolder_Keystone_2460_1xAA; MPN 2460
BT2: AA SAFT; MPN LS14500 / SL760
C1, C4, C10: 1nF; C_0402_1005Metric; not fitted
C2, C3: 100nF; C_0402_1005Metric; not fitted
D1, D2, D4: CDSU101A; D_SOD-523; MPN CDSU101A; not fitted
D3: LED; LED_0603_1608Metric; MPN LG L29K-G2J1-24-Z; not fitted
D5, D6: Zener Prot 5V; D_SOD-523; MPN EDZVT2R5.1B; not fitted
H1, H2, H3: 9774025360R; Mounting_Wuerth_WA-SMSI-M3_H2.5mm_9774025360; MPN 9774025360R
J1: JLINK; SEXY_pinpogo; not fitted
Q1: MMBT3906; SOT-23; MPN MMBT3906-7-F; not fitted
Q2: Q_Photo_NPN; PHOTOTRANS_1708Metric; MPN ALS-PT19-315C/L177/TR8; not fitted
Q3: IRLML6401; SOT-23; MPN IRLML6401; not fitted
R1, R5, R6, R8, R11, R12: 10k; R_0402_1005Metric; not fitted
R2, R9: 10k; R_0603_1608Metric; not fitted
R3, R10: 1M; R_0402_1005Metric; not fitted
R4: 1k; R_0402_1005Metric; not fitted
R7: 470R; R_0402_1005Metric; not fitted
RST1: B3U-1000P; SW_SPST_B3U-1000P-B; MPN B3U-1000P-B; not fitted
SW1: B3U-1000P; SW_SPST_B3U-1000P-B; MPN B3U-1000P-B; not fitted
TP2: VCC; TestPoint_Pad_D1.0mm
TP3: IO; TestPoint_Pad_D1.0mm
TP4: CLK; TestPoint_Pad_D1.0mm
TP5: GND; TestPoint_Pad_D1.0mm
TP6: RST; TestPoint_Pad_D1.0mm
TP7: CPARA; TestPoint_Pad_D1.0mm
TP8: PWM; TestPoint_Pad_D1.0mm
TP9: RX; TestPoint_Pad_D1.0mm
TP10: TX; TestPoint_Pad_D1.0mm
U1: SHTC3; Sensirion_DFN-4-1EP_2x2mm_P1mm_EP0.7x1.6mm; MPN SHTC3; not fitted
X1: KC3225K75.0000C1GE00; Oscillator_SMD_SeikoEpson_SG8002CE-4Pin_3.2x2.5mm; MPN KC3225K75.0000C1GE00; not fitted

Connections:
+3V6: BT1.1 (+), BT2.1 (+), C2.1, D2.1 (K), J1.1, Q3.2 (S), R5.2, R6.1, R8.1, TP2.1, U1.1 (VDD); also elsewhere on the board
BTN1: SW1.1; also elsewhere on the board
CPARA: D1.2 (A), D5.1 (K), H1.1, Q1.2 (E), R2.2, TP7.1
GND: BT1.2 (-), BT2.2 (-), C1.2, C2.2, C3.2, C4.2, C10.2, D2.2 (A), D3.1 (K), D5.2 (A), D6.2 (A), H2.1, J1.3, J1.5, J1.7, J1.8, J1.9, Q1.3 (C), R3.2, R7.1, R10.2, R11.1, RST1.2, SW1.2, TP5.1, U1.4 (VSS), X1.2 (GND); also elsewhere on the board
HF_OSC: Q3.1 (G), R8.2; also elsewhere on the board
LED: R4.2; also elsewhere on the board
unnamed: D3.2 (A), R4.1
unnamed: D4.2 (A), D6.1 (K), H3.1, R9.2
unnamed: Q1.1 (B), R1.1
unnamed: C3.1, Q3.3 (D), R12.2, X1.1 (EN), X1.4 (Vdd)
unnamed: R9.1, X1.3 (OUT)
PHOTO_OUT: Q2.2 (E), R7.2; also elsewhere on the board
PHOTO_V: Q2.1 (C); also elsewhere on the board
PWM: R1.2, R2.1, TP8.1; also elsewhere on the board
SCL: R6.2, U1.2 (SCL); also elsewhere on the board
SDA: R5.1, U1.3 (SDA); also elsewhere on the board
SENS_OUT: C1.1, D1.1 (K), R3.1; also elsewhere on the board
SENS_OUT_HF: C4.1, D4.1 (K), R10.1; also elsewhere on the board
SENS_OUT_HF_REF: C10.1, R11.2, R12.1; also elsewhere on the board
SWDCLK: J1.4, TP4.1; also elsewhere on the board
SWDIO: J1.2, TP3.1; also elsewhere on the board
SWO: J1.6
UART_RX: TP9.1; also elsewhere on the board
UART_TX: TP10.1; also elsewhere on the board
~RESET: J1.10, RST1.1, TP6.1; also elsewhere on the board

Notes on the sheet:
Reset switch
Fast discharge on PWM’s low cycle
Temperature and humidity sensor
Test pads
Smokey sacrificial Reverse current detector
Programming port
Light sensor
Battery Holder
High Frequency probe
User button
LED
Parasitic capacitor sensing

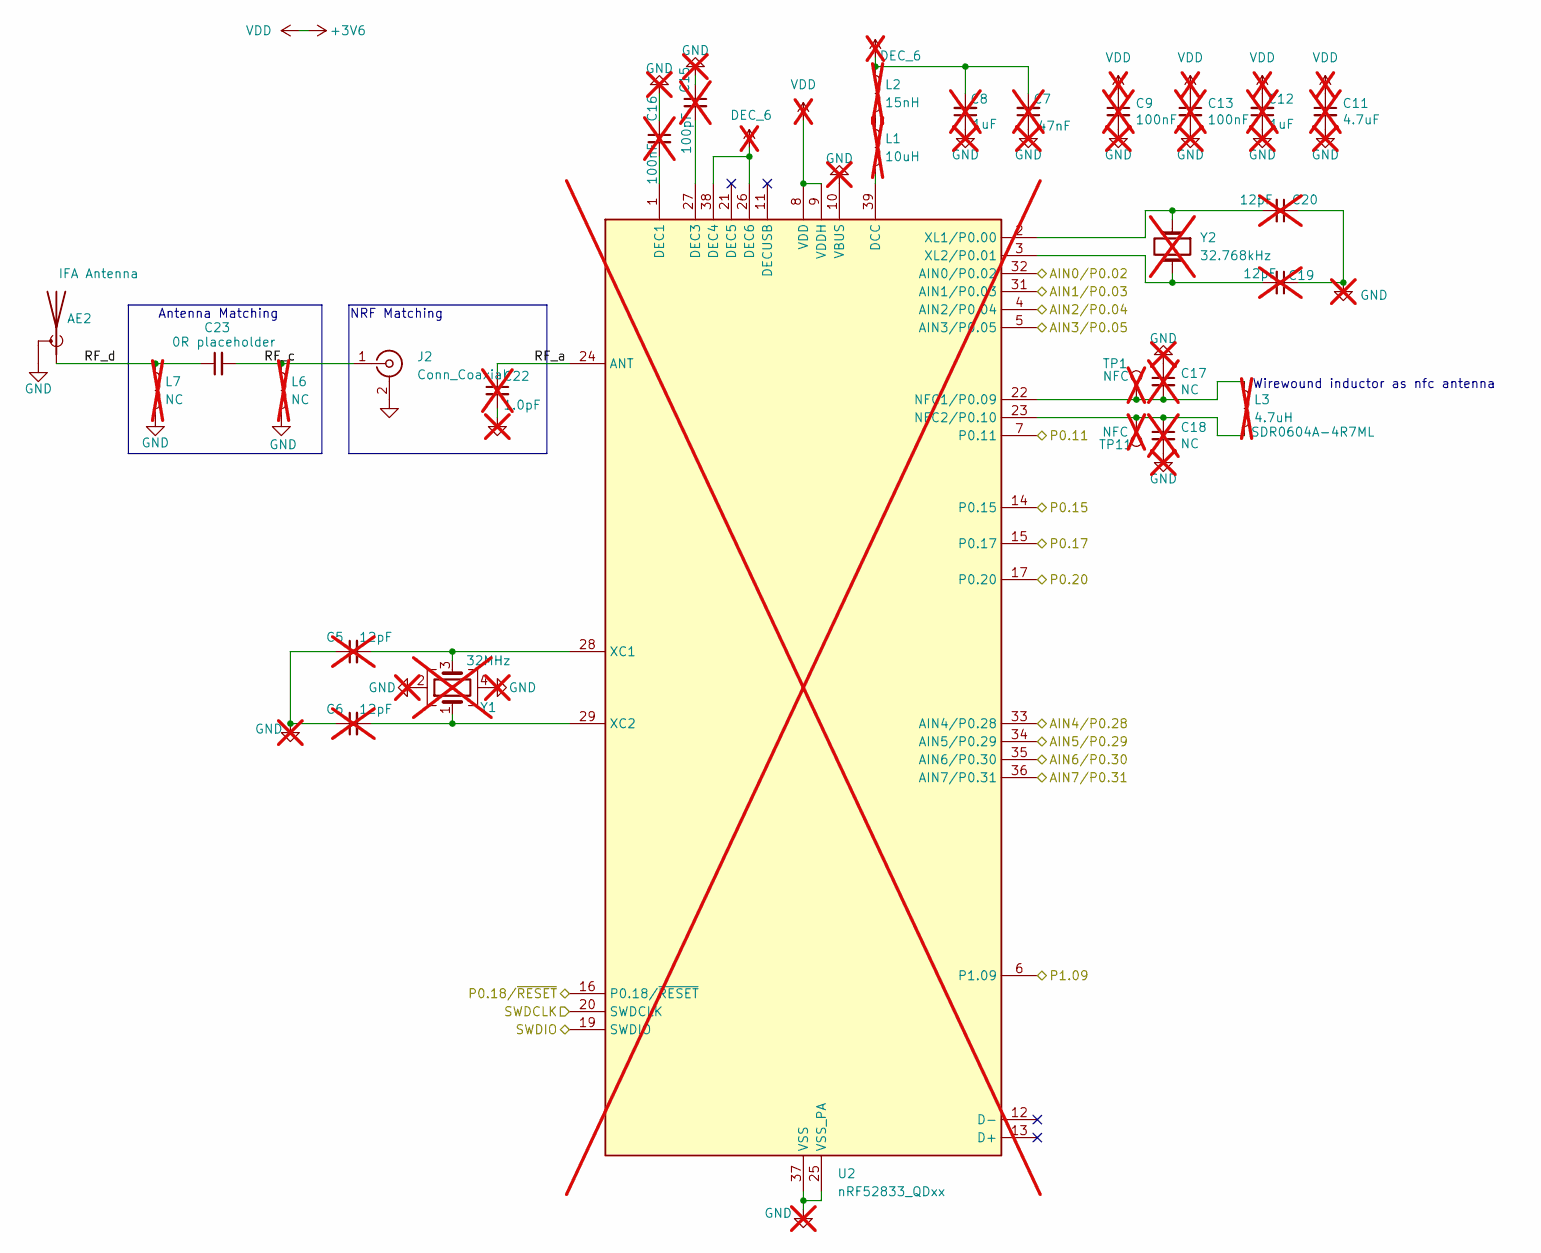
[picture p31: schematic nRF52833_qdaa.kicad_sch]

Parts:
AE2: IFA Antenna; IFA-0.12mm
C5, C6, C19, C20: 12pF; C_0402_1005Metric; not fitted
C7: 47nF; C_0402_1005Metric; not fitted
C8, C12: 1uF; C_0402_1005Metric; not fitted
C9, C13, C16: 100nF; C_0402_1005Metric; not fitted
C11: 4.7uF; C_0603_1608Metric; not fitted
C15: 100pF; C_0402_1005Metric; not fitted
C17, C18: NC; C_0402_1005Metric; not fitted
C22: 1.0pF; C_0402_1005Metric; MPN GJM1555C1H1R0WB01D; not fitted
C23: 0R placeholder; C_0603_1608Metric
J2: Conn_Coaxial; U.FL_Hirose_U.FL-R-SMT-1_Vertical
L1: 10uH; L_0603_1608Metric; not fitted
L2: 15nH; L_0402_1005Metric; not fitted
L3: 4.7uH; L_Bourns_SDSS604A; MPN SDR0604A-4R7ML; not fitted
L6, L7: NC; L_0603_1608Metric; not fitted
TP1, TP11: NFC; TestPoint_Pad_D1.0mm; not fitted
U2: nRF52833_QDxx; QFN-40-1EP_5x5mm_P0.4mm_EP3.6x3.6mm_ThermalVias; MPN nRF52833_QDAA; not fitted
Y1: 32MHz; Crystal_SMD_2016-4Pin_2.0x1.6mm; MPN XRCGB32M000F2P01R0; not fitted
Y2: 32.768kHz; Crystal_SMD_2012-2Pin_2.0x1.2mm; MPN CM8V-T1A-32.768KHZ-9PF-20PPM-TA-QC; not fitted

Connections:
+3V6: C9.1, C11.1, C12.2, C13.1, U2.8 (VDD), U2.9 (VDDH), U2.18 (VDD), U2.30 (VDD), U2.40 (VDD); also elsewhere on the board
/nRF52833_qdaa/RF_a: C22.1, U2.24 (ANT)
/nRF52833_qdaa/RF_c: C23.2, J2.1 (In), L6.1
/nRF52833_qdaa/RF_d: AE2.1 (A), C23.1, L7.1
BTN1: U2.6 (P1.09); also elsewhere on the board
DEC_6: C7.2, C8.2, L2.1, U2.26 (DEC6), U2.38 (DEC4)
GND: AE2.2 (Shield), C5.1, C6.1, C7.1, C8.1, C9.2, C11.2, C12.1, C13.2, C15.1, C16.1, C17.1, C18.2, C19.1, C20.1, C22.2, J2.2 (Ext), L6.2, L7.2, U2.10 (VBUS), U2.25 (VSS_PA), U2.37 (VSS), U2.41 (VSS), Y1.2, Y1.4; also elsewhere on the board
HF_OSC: U2.36 (AIN7/P0.31); also elsewhere on the board
LED: U2.31 (AIN1/P0.03); also elsewhere on the board
unnamed: L1.1, L2.2
unnamed: L1.2, U2.39 (DCC)
unnamed: C16.2, U2.1 (DEC1)
unnamed: C15.2, U2.27 (DEC3)
unnamed: C17.2, L3.1, TP1.1, U2.22 (NFC1/P0.09)
unnamed: C18.1, L3.2, TP11.1, U2.23 (NFC2/P0.10)
unnamed: C5.2, U2.28 (XC1), Y1.3
unnamed: C6.2, U2.29 (XC2), Y1.1
unnamed: C20.2, U2.2 (XL1/P0.00), Y2.1
unnamed: C19.2, U2.3 (XL2/P0.01), Y2.2
PHOTO_OUT: U2.32 (AIN0/P0.02); also elsewhere on the board
PHOTO_V: U2.33 (AIN4/P0.28); also elsewhere on the board
PWM: U2.35 (AIN6/P0.30); also elsewhere on the board
SCL: U2.15 (P0.17); also elsewhere on the board
SDA: U2.17 (P0.20); also elsewhere on the board
SENS_OUT: U2.34 (AIN5/P0.29); also elsewhere on the board
SENS_OUT_HF: U2.4 (AIN2/P0.04); also elsewhere on the board
SENS_OUT_HF_REF: U2.5 (AIN3/P0.05); also elsewhere on the board
SWDCLK: U2.20 (SWDCLK); also elsewhere on the board
SWDIO: U2.19 (SWDIO); also elsewhere on the board
UART_RX: U2.7 (P0.11); also elsewhere on the board
UART_TX: U2.14 (P0.15); also elsewhere on the board
~RESET: U2.16 (P0.18/~RESET); also elsewhere on the board

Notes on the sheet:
Wirewound inductor as nfc antenna
NRF Matching
Antenna Matching

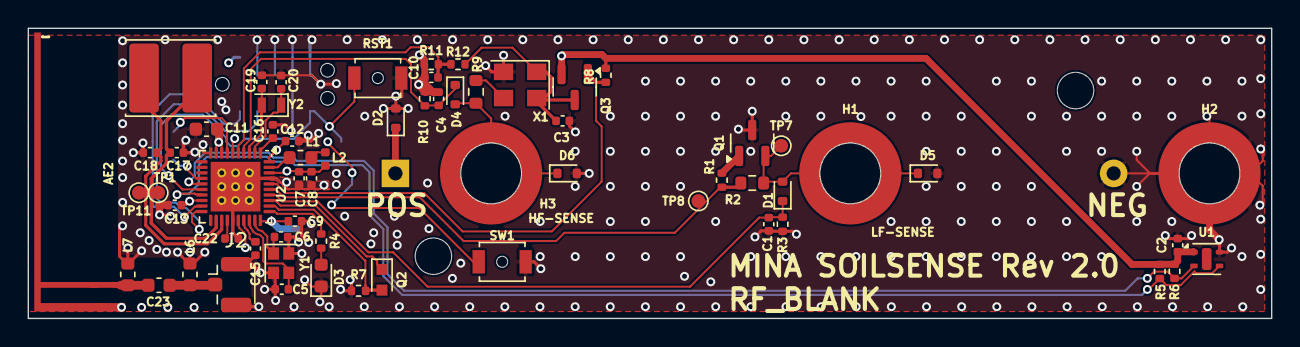
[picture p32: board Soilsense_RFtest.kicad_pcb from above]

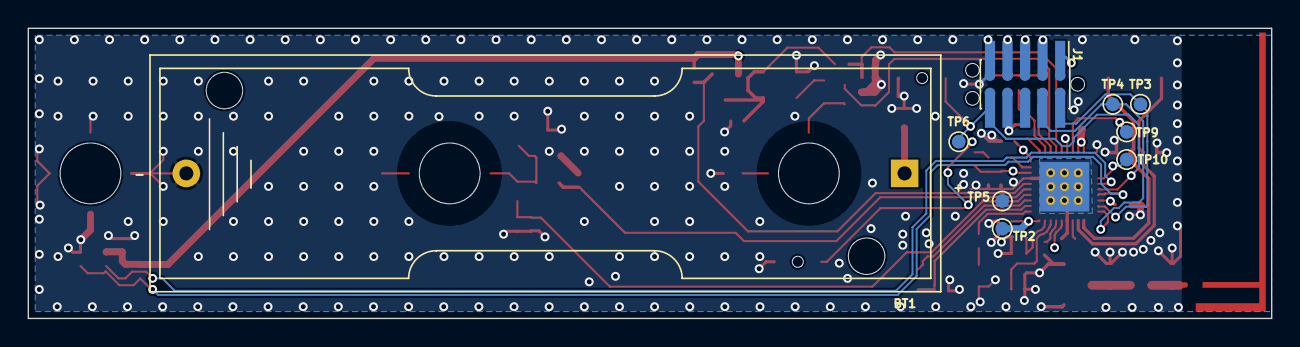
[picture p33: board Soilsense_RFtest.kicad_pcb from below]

Board: 4 copper layers, 90.0 x 21.0 mm, 72 parts (9 on the bottom side), 38 nets.

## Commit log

2024-08-15 NFC update
    [Soilsense.kicad_pcb, Soilsense.kicad_sch, nRF52833_qdaa.kicad_sch]
2024-10-10 Small changes
    [ADC.kicad_sch, ENV_SENSOR.kicad_sch, GAS_SENSOR.kicad_sch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]
2024-10-11 Rev 2.0
    [bom.csv, designators.csv, positions.csv]
2024-10-11 Added antenna script
